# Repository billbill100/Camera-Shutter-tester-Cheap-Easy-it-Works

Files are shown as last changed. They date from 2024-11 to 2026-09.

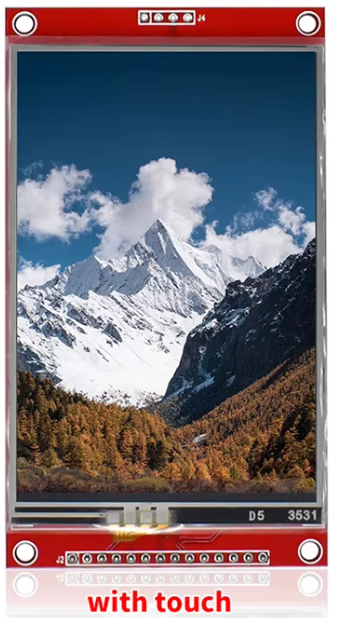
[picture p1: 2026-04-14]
ESP32_V4/3d_print_files/ShutterTesterCase3dPrinted 3_5/photos/Screenshot 2026-04-12 164409.png

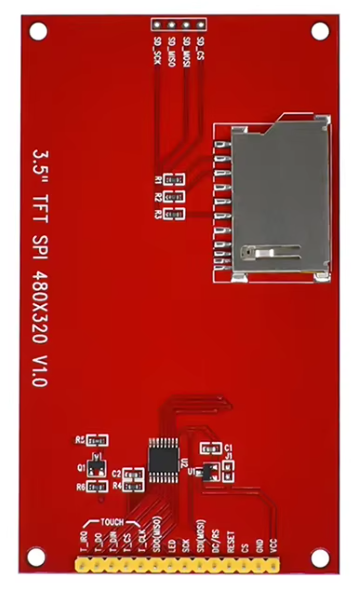
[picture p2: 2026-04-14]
ESP32_V4/3d_print_files/ShutterTesterCase3dPrinted 3_5/photos/Screenshot 2026-04-12 164905.png

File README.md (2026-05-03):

# Camera Shutter Tester -Cheap-Easy-it-Works
ESP32 or Arduino based shutter tester using three sensors (ESP32) or two sensors (Ardiuno).

Important note: - Both ESP32 and Arduino based Shutter Testers are available.

The ESP32 processor is faster and has more flash memory than the Arduino. Therefore the ESP32 based Shutter Tester, allowing greater functionality, including a colour screen, flash sync testing, camera diagnostics and data logging.

The Arduino version is simpler to build, so those with limited experience with microcontrollers & building electronic devices, may find this easier for a first time build.

The Arduino version uses the same processing algorythm as the ESP32 version, so gives accurate shutter meaurements, unlike most (all) of the other Arduino testers found on the interweb.

The latest versions are Version 4 for ESP32 and Version 2 for Arduino.

The use of three lasers & three sensor (two for Arduino) allows for correct travel time measurement for each shutter curtain of a focal plane shutter, which is most important to ensure even exposure across the frame and to detect curtain bouncing.

DIY builds that use a single sensor or Audacity simply will not work. Both shutter curtains must be set to travel at the same speed, which is simply not measurable using just one sensor. Similarly there will always be an inherent error when measuring a single light point with a sensor, which of course will be wider than a single photon. This error can be mathematically calculated and corrected using a simple algorithm, if multiple sensors are used.

The shutter tester is designed to use cheap, easy to obtain parts from Aliexpress. 
A guide to building a suitable enclosure using a project box or optional 3d printing, are included. 
The builder can change or adapt this for their needs, or indeed not use an enclosure at all. Photos of builders different ideas are included.

A comprehensive build guide thread & user group can be found on on Photrio.

# https://www.photrio.com/forum/threads/build-a-shutter-tester-for-focal-plane-shutters-cheap-easy-it-works.197756/

Note both ESP32 and Arduino versions require a one-time pass key. This is supplied free of charge upon request.

On a new build, an authorisation code will be displayed. Send this to me via PM (Photrino is the quickest way) and a user passkey will be sent by return.

I would really be grateful if you start to build the shutter tester, that you go to the Photrio thread and say hi. Also please post photos of your completed tester.

Please refer to Photrio for further build help & to let us know you are building the tester..

 Github has no direct means of contact, my email address is
# bill bill github at gmail dot com
(remove spaces & change @ . )

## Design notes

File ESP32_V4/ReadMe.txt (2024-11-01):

The latest build guides and firmware for Version 4 of the Shutter Tester are listed here.

The build guides have been updated to Version 4, showing the use of JST HX connectors, rather than Dupont wires.

The only hardware change from V3 to V4 is the addition of a rotary encoder 
and the use of JST HX connectors and wiring colours in place of Dupont.
(Which does not effect functionality).

With the addition of a rotary encoder, V3 hardware will work with V4 firmware,
without any other changes.

Note V4 firmware requires the use of a one-time passkey.
This is issued free of charge upon request.

Any questions, ask in the photrio forum
https://www.photrio.com/forum/threads/build-a-shutter-tester-for-focal-plane-shutters-cheap-easy-it-works.197756/page-21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

-----------------------------------------------------------   

Version 4 Firmware

Hardware Changes:-
Rotary Encoder added (mandatory)
LCD Depreciated.

Wiring colour changes to match JT HX pin-headers. Makes wiring neater. 
(Dupont wires can also be used).

Note to convert version 3 hardware to version 4, just add the rotary encoder :o) 

Firmware Changes:-

Baud rate changed to default value of 115200
Leaf shutter testing added.
Sensor spacing is now user-set.
Sensor Reading validity checking updated.
Test result analysing updated (bounce, slow curtain etc).

Alignment screen replaced with all new Setup & Alignment screen.
LCD updated to show & allow change of settings.
PC screen updated to show & allow change of settings.
Rotary encoder used to select & change settings.

Original 'Detailed' TFT screen has been suplemented with a new 'Simple' TFT screen with large typeface, 
replacing the LCD. Changing between Detailed & Simple screen is by a simple button-push, anytime.

Horizontal/vertical shutter selecton removed.
Replaced by user set sensor spacing.

Auto single-sensor sensing removed.
Repaced by user selecting Single Sensor, Leaf or Focal Plane shutter.

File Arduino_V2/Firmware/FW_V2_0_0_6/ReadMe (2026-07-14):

IMPORTANT
This current version 2_0_0_6 is a quick beta version.

Needed to issue it due to issue with 2_0_0_5 would not work with a new Nano board.

Please use this version for now & check back for the fully tested version.

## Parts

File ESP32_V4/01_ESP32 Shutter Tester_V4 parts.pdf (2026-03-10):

I would really be grateful if you start to build the Shutter, that you go to the Photrio thread and say hi. Also please post photos of your completed tester.
Build a shutter tester for Focal Plane shutters - Cheap, Easy & it Works | Page 18 | Photrio.com Photography
Forums (https://www.photrio.com/forum/threads/build-a-shutter-tester-for-focal-plane-shutters-cheap-easy-it-works.197756/page-18)

Please refer to Photrio for further build help

### ESP32 Shutter Tester V4 Parts V1.7 03 03 2026

Below are links to the parts required to make the ESP32 Shutter Tester.

Not all of the parts will be necessary and will depend if you choose to use the project box, or 3d printed case, pcb or expansion board etc. These are detailed with each part.

Links are valid now, but of course could become dead in the future.

Links are for AliExpress suppliers and are a guide only.

Use a supplier who ships to your country.

Note, often if buying from AliExpress, there is a ‘Choice’ free express shipping option, if buying parts over a set value.

### ESP32 NodeMcu board. 38 pin version. USB-C CP2102

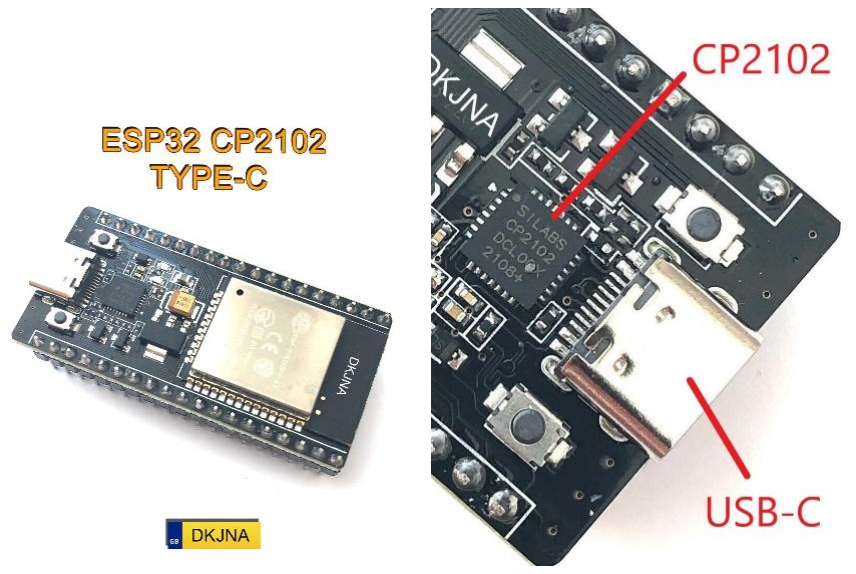
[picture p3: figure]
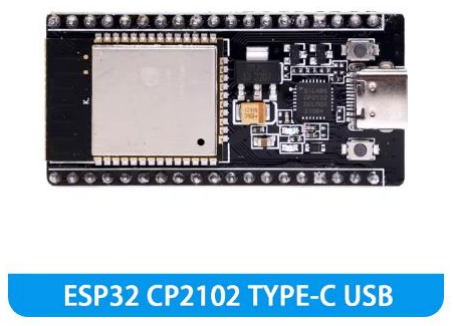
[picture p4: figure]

IMPORTANT. There are multiple variants of this board. Get 38 pin USB-C and CP2102 chip.
The board should NOT have mounting holes. Overall width is 25mm and pin spacing between the rows is 0.9” or 23mm (sometimes listed as 22.5mm)

Note: - The guides have been written for this specific board type. Boards which differ with their USB chip and/or connector may still work, but the guides will not detail different driver installs or pin layout differences.

### ESP32 Expansion (breakout) Board

### ESP32 prototype/breakout board (38 pin screw-terminal version)

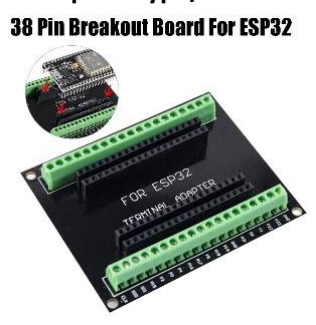
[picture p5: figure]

Note: - this screw type breakout board was originally only available in 38-pin form and for the 22.5mm spaced ESP32 board. However, recently, a 30-pin version has become available, as well as a version for 25mm spaced boards.
This is causing confusion in China. My last few orders of this board have been incorrect. One time sending a purple board with pin headers and most recently a 30-pin board, blue in colour but in a sealed bag marked 38P

Important update There seems to be a big mess-up in China, with both 22.5mm and 25mm expansion boards being mixed. Despite my last few orders from a supplier with measurements written on their board stating it was 22.5mm, the expansion board was for the wider 25mm ESP32 board.

An optional choice is to replace the Expansion Board with a custom PCB.
Details below:

A custom pcb replacing the expansion board has been designed. Both the ESP32 and tft screen plug directly into it, with all wiring between the two, pre-connected on the board.
All other wiring, for the sensor etc, are accessed by screw-terminals as per the expansion board.

The pcb can only be ordered directly from the originator of The Shutter Tester (contact via Photrio).
See additional ‘The Shutter Tester pcb’ document on Github.

There is a newer V4 ESP32 board available. It has 25mm spacing, USB-C and the 2102 USB driver.
It is also cheaper. One issue with this board is that the pcb is too narrow to mount directly onto the TFT mounting bolts. So the 3d printed expansion board frame will be required.
Personally, I have not yet tried it, but it may be the way forward to overcome the issues with the current expansion board. Link is to the Aliexpress page. If you try it, get the 32D Type-C KIT which includes ESP32 board and the expansion board.
ESP32 Development Board with GPIO Expansion Board Kit ESP32-WROOM-32D BT Wifi Module USB Type-C 38PIN CP2102 ESP32-DevKitC - AliExpress 502 (https://www.aliexpress.com/item/1005007820261192.html?mp=1) ----------------------------------------------------------------------------------------------------------------------------------------------

Update 06/02/2026
A recent builder has used this link and reports they ordered the expansion board (not breakout board) and the ESP32 from here and they were the correct ones.

ESP32 Nodemcu ESP32 Expansion Board ESP32-S 32Mbit SPI Flash ESP32 Bluetooth Wifi ESP 32 Bluetooth (https://www.aliexpress.com/item/1005008419095315.html)

Module ESP32 30Pin 38Pin - AliExpress (https://www.aliexpress.com/item/1005008419095315.html)

Laser tx & rx module.
Three Laser tx and rx module pairs are required.

The sensor is supplied loose. ENSURE YOU INSERT IT THE CORRECT WAY ROUND!!!. Little bubble lens points towards the header pins.

Arduino Laser Sensor Receiver | Laser Transmitter Module Arduino - 10pcs/set Sensor - Aliexpress (https://www.aliexpress.com/item/1005003318800536.html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)

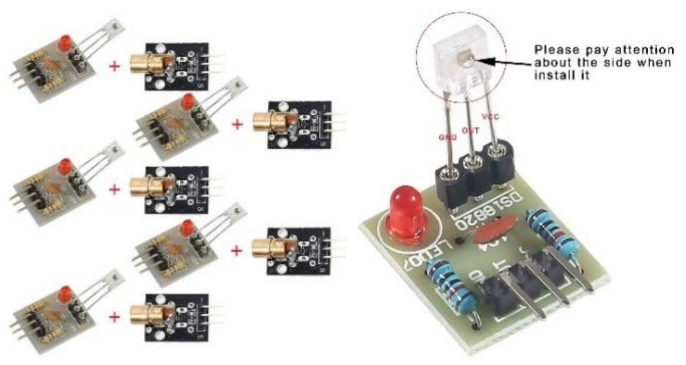
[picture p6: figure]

Buttons.
Below is a link to buttons which may be purchased as a 6-pack. Note they melt very easily with a soldering iron, so one must be proficient & quick when making the soldered joints. An alternate is to buy a 5-button module, which uses Dupont/JST header pins.

6piece Mini 12mm Waterproof Momentary On/off Push Button Round Switch Pbs-33b Kit White Black Red Yellow Blue Green - AliExpress (https://www.aliexpress.com/item/1005006228814305.html)

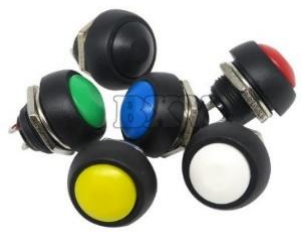
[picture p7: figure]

JST XH 2.54MM Connector kit.
This kit comes with connectors pre-crimped onto the wires. This allows the connectors to simply be pushed into the plastic housings, allowing for different connector sizes and colour combinations to be made.

Note: - There are no brown wires in these kits. (see below)*

The TFT needs a 14-pin connector. This is made by using two 7-way connectors from the kit and carefully cutting off the lips on the connectors, so they sit side-by-side. (Or you can buy a separate 8-way JST XH connector and use in combination with a 5-way connector, which fit either side of the unused pin on the TFT).

2.54mm XH Connector Socket Kit with 22AWG Pre-Crimped Wire Cable JST XH 2/3/4/5/6/7 Pin Housing Male Female Adapter Cable - AliExpress 13 (https://vi.aliexpress.com/item/1005008117970148.html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)

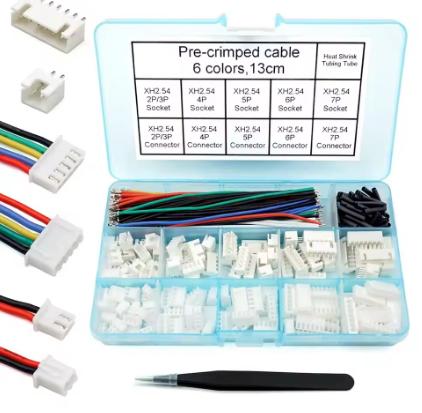
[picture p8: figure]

*JST XH 2.54mm wires. Single colours, Select 30cm Double Head Brown. OPTIONAL – See below
Note: The schematic uses Brown colour to distinguish 3V power and 5V (Red).

To save buying additional wires, which have additional postage costs,
Red can be used for both 3V and 5v, but BE CAREFUL with connections.

10Pcs SH1.0mm Jst 1.25mm PH2.0mm XH 2.54mm Terminal Wire Single / Double Head Electronic Connecting Cable Without Shell 10-30CM - AliExpress 13 (https://vi.aliexpress.com/item/1005006316801315.html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)

TFT display.

### 4.0 inch SPI Touch screen Module 480*320 TFT display ILI9488

Board size is 108.04 X 61.74

Note: - there are many similar panels but they have different driver chips (ILI9488), the Shutter Tester only works with this specific screen. Please ensure you correctly order the screen. The AliExpress web sites often list similar but different boards.

New 4.0 inch SPI serial port LCD Touch screen Module 480*320 (Free Shipping)TFT display ILI9488 HD Electronic STM32 ESP32 AR C51 - AliExpress 502 (https://vi.aliexpress.com/item/1005005791515997.html)

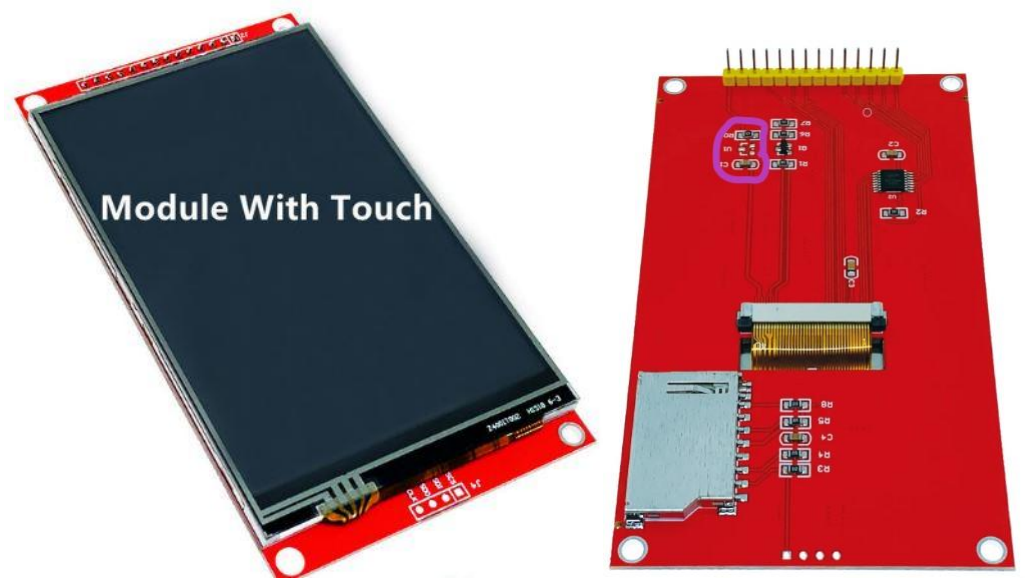
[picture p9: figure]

Rotary Encoder.
Ensure you purchase the one mounted onto the blue pcb. As this has in-built pullup resisters & capacitors.
Rotating Potentiometer Knob Cap Digital Control Module Rotary Encoder Controller Switch 5V Diy Kit EC11 For Arduino PCB Board - AliExpress (https://www.aliexpress.com/item/1005006332290643.html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)

### USB extension cable. 0.2M length. (Optional)

Makes a neat job by bringing the USB port of the ESP32 board to the side of the project box.

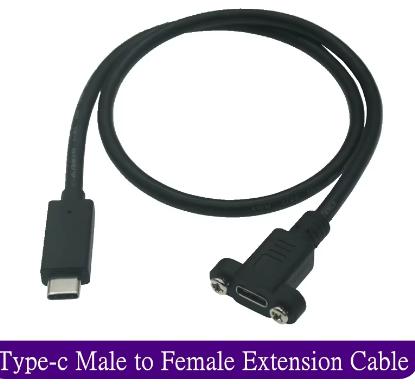
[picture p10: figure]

1M 0.5M Panel Mount Type-C USB-C Male To Female Extension Cable With Screw Hole Lock Connector Cable Spacing 18mm - AliExpress 7 (https://vi.aliexpress.com/item/1005003311183241.html)

Light sensor. (Optional).
GY-301 LIGHT SENSOR MODULE
TZT GY-302 BH1750 BH1750FVI light intensity illumination module for arduino 3V-5V (aliexpress.com) (https://www.aliexpress.com/item/1005005850310036.html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)


LED Matrix Module. (Optional).
Gives a visual indication of shutter speed, works like the old idea of photographing a scanning CRT.

New version – requires header pins soldering
MAX7219 Dot Matrix Microcontroller Display Module Together For Arduino - AliExpress 502 (https://vi.aliexpress.com/item/1005006189776556.html?scm_id=1007.40000.326746.0&scm-url=1007.40000.326746.0)


Project Box. (not required if 3d printing a case).
There are all sorts of shapes & sizes of project boxes. The 158 x 90 x 60 is a good size.
The screen must be positioned as high as possible, to leave enough space below, for two rows of buttons. A suggested layout & template can be found in the ‘Build a Box’ document.
Black Box Outdoor Waterproof Case Plastic Box Electronic Project Case Instrument Waterproof Junction Box Housing - AliExpress (https://www.aliexpress.com/item/1005005622148025.html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)


Note: a 3d printable enclosure is also available. Files are in the Github.

Project box for Light-Meter 55 X 35 X 20. (Optional).
If using the Light-Meter module, this box is the ideal size.
1pc Waterproof Black/white Housing Instrument Case ABS Plastic Project Box Storage Case Enclosure Boxes Electronic Supplies - AliExpress (https://vi.aliexpress.com/item/1005005467340473.html)


Note: - if using the LED matrix, a suitable project box will also be required.

### PC sync cable (flash) (Optional)

For testing flash synchronising. A 3.5mm socket will also be required.


### 3.5mm socket. (Optional)

If using the Flash Sensor, a 3.5MM socket is required. PJ-391 for the sockets.
10PCS 2.5 3.5MM Headphone Jack Audio Video Female Dual Channel Stereo Jack Jack Socket Stereo Solder Panel Mount PJ-210B PJ-392 - AliExpress (https://vi.aliexpress.com/item/1005006181883514.html?mp=1)

Multicore Wire.
Used to connect the sensors to the breakout board and button wiring.
5/10Meter 22 AWG 2Pin 3Pin 4Pin 5Pin 6Pin Electronic Cable Extension Wire Color Line for 5050 3528 RGBW RGB CCT LED Strip Lights - AliExpress 13 (https://vi.aliexpress.com/item/1005007156114505.html?mp=1)

More expensive but has outer insulation. Good for the external cable between project box & sensors.
5-50m LED Strip Extension Cable Flexible Multi 2 3 4 5 6 7 8 9 10 Core Insulate Audio Electrical Wire For Speaker LED Lights Bar - AliExpress 13 (https://vi.aliexpress.com/item/1005006340775911.html?scm_id=1007.40000.327270.0&scm-url=1007.40000.327270.0)

Connector-block - 2 pole. (Not required for PCB version)
There are many 3V & 0V wires to be connected. The quickest way is to use a lever-locking connector as shown below. As the wires are thin, many can be put into each terminal, so a 2-terminal type is fine. Use one with more terminals if you like

Alternates are to the solder the wires together, or use a joining block.

10-75pcs Orange Universal Type Quick Plug-in Terminals,Electrical Equipment Connectors,Wire Connector Terminals,250V/32A - AliExpress (https://www.aliexpress.com/item/1005006271613810.html?scm_id=1007.40050.354490.0&scm-url=1007.40050.354490.0)


Shrink Tube. (Optional).
It is useful cut into small lengths of 5mm, and placed along the cables, to hold them into a bunch, for neater wiring. Note shrink tube also comes with the JST connector kit.

Also useful for covering soldered joints on wires, if using JST connectors for the sensors, for example, which then need soldering to the multicore cable.

127pcs/lot 2:1 Thermoresistant tube Shrink wrapping Black heat shrink Sleeving set Wire Cable Polyolefin Wrap Tubing - AliExpress (https://vi.aliexpress.com/item/1005006381007308.html)


Plug & Sockets.
The cable to the sensors/Lasers & Light-meter can be hardwired directly to the expansion board or connected via plugs & sockets.

Use 8 pin plugs & sockets for cabling to the Sensor/Laser frame. Five of the eight pins will be used.

There will be three spare pins. Another 8-pin plug & socket can be used for the light senor, using the three spare pins and sharing the 0V pin.

Ensure that the 3.3V and 5V are given their own dedicated pins and these pins are not used for data in another connector.

If using the LED matrix, use a connecter with a different number of pins, to avoid the possibility of it being plugged in to the wrong socket.

An alternate would be using a different connector type for each of the outputs (8-pin for sensor/Laser frame, six-pin for light-meter, 5-pin for Matrix, for example)

Solder Connector DIN 3 4 5 6 7 8 Pin DIN Male Female Plug with Plastic Handle + Female Socket Hulled Panel Mount Chassis a1 - AliExpress 13 (https://vi.aliexpress.com/item/1005004311168264.html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)


### M3 Bolts, Nuts, Washers. 25mm & 12MM Length Stainless Steel

M3 bolts can be used to mount the tft screen into the project box or 3d printed case. Slightly elongating the mounting holes on the expansion board, allows it to also be easily mounted onto the same bolts. 25mm length is ideal for this. 12mm can be used to mount the Din sockets, if using them.
Don’t forget to also order washers & nuts.

Nuts & bolt set
M2 M3 M4 M5 M6 Nuts and Bolts Set 304 Stainless Steel Hexagon Button Hex Socket Fairing Bolt Assortment Kit Thread Allen Screws (https://vi.aliexpress.com/item/1005005377559662.html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)

Bolts only

5-50p ISO7380 M2 M2.5 M3 M4 M5 M6 M8 304 A2 Round Stainless Steel or Black G10.9 Hex Socket screw Button Head Allen Bolt Screws - AliExpress 13 (https://vi.aliexpress.com/item/32810852732.html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)

Washers
GB97 DIN125 A2-70 304 Stainless Steel Flat Washer Plain Gasket M1.6 M2 M2.5 M3 M3.5 M4 M5 M6 M8 M10 M12 M14 M16 M18 M20 M22 M24 - AliExpress 13 (https://vi.aliexpress.com/item/32975752411.html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)

Nuts
100pcs/lot Metric thread DIN934 M2 M2.5 M3 M3.5 M4 M5 M6 Steel Hex Nuts - AliExpress 13 (https://vi.aliexpress.com/item/1005007856981951.html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)

Lifting platform for adjusting height of camera. (3d print files available, to make top, to hold camera)
Plastic Lift Table Woodworking Carving Laser Level Bracket Plastic or Aluminum Meterial Device Height Adjustment Lift Platform - AliExpress 1420 (https://www.aliexpress.com/item/1005010660465390.html)


Items for 3d printed case and 3d printed sensor & Laser enclosure. (Optional).
Lasers. Required for the 3d printed the Laser enclosure.
Order the 5v Lasers.
5pcs Adjustable Laser Diode 650nm 6mm 3/5V 5 Million Watt Red Point Line Laser Diode Module Red Copper Head
- AliExpress 1420 (https://www.aliexpress.com/item/1005003538326411.html)


Pcb strip-board. Required for the 3d printed sensor enclosure.
This board has each row of holes electrically connected.
5/10PCS DIY 6.5x14.5 6.5*14.5CM Prototype Paper PCB Universal Experiment Matrix Circuit Board Single Row Continuous Hole - AliExpress 502 (https://www.aliexpress.com/item/1005008734573412.html)


0.1uF Capacitors. (104 100NF) Required for the 3d printed sensor enclosure.
100PCS 100nF 0.1uF 0.1 uF 104 50V 2.54mm Dip Mono Monolithic Capacitors - AliExpress (https://www.aliexpress.com/item/1005005610707847.html?curPageLogUid=fK9XBGJN9GK5)


10k resisters Required for the 3d printed sensor enclosure.
100PCS/Lot Metal Film Resistor 1/4W 1% 100R 220R 1K 1.5K 2.2K 4.7K 10K 22K 47K 100K 100 220 1K5 2K2 4K7 Ohm Resistance 1R~22M - AliExpress (https://www.aliexpress.com/item/1005006898731441.html?curPageLogUid=0MNUTMG3vVjt)


2mm screw selection box. Used to assemble the case and enclosures.
800pcs M2(2mm) Self Tapping Wood Carbon Steel Phillips Pan Head Self Tapping Screws Assortment Kit M2*4/5/6/8/10/12/16/20mm - AliExpress 13 (https://www.aliexpress.com/item/1005008090724184.html)


M5 X 35mm nut, bolt & washer with 10mm hex head.
This is for the camera steady, which sits on the lifting platform.

### _________________________________________________

### Additional useful parts

Lifting platform. Used to place the camera on and allows height adjustment.
Plastic Lift Table Woodworking Carving Laser Level Bracket Plastic or Aluminum Meterial Device Height Adjustment Lift Platform - AliExpress 1420 (https://www.aliexpress.com/item/1005010660465390.html)


Drill bits for making holes in the project box. (Not required for 3d printed case)
3MM for bolts, 7mm for encoder & flash socket, 13mm for the buttons, 15MM for Din sockets.

3-12mm Three-point Woodworking Drill Hole Opener Twist Drill Bit Practical Wood Milling Cutter Multifunctional Drilling Tools - AliExpress (https://www.aliexpress.com/item/1005006103163521.html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)

13mm bit.
10-35mm Woodworking Twist Drill Bit Set Long Four-Slot 6.35mm Shank Carbide Drill Bit Hole Saw For Door Lock Wood Slotting Tools (aliexpress.com) (https://vi.aliexpress.com/item/1005003944211081.html)

Glue Gun.
Cheap glue gun, but surprisingly it works ok.
20W Hot Melt Glue Gun DIY Mini Household Industrial Guns Heat Temperature Thermo EU Electric Repair Tool Use 7mm Glue Sticks - AliExpress (https://www.aliexpress.com/item/1005005795878015.html)

Don’t forget the glue :o)
T TOVIA 60pcs/120pcs Hot Melt Glue Sticks 7mm Hot Glue Sticks Rod for Craft Album Repair Tools Hot Glue Gun Sticks - AliExpress (https://vi.aliexpress.com/item/1005005713317179.html?mp=1)

### Wire Strippers. Model 3001D

The JST HX wires are very thin 22AWG. A good quality wire stripper will be required. An alternate is to use a sharp scalpel or Stanley knife blade

Pro'sKit 8PK-3001D 8PK-3002D high quality electronic wire stripper cutting pliers (AWG 30/28/26/24/22/20 precision pliers - AliExpress 1420 (https://vi.aliexpress.com/item/1005007370026286.html?mp=1)

Stanley knife & plasters trowel.
To safely make square cut-out for tft in the project box. Source locally.

Soldering Iron Kit.
Cheap soldering iron kits are available on Aliexpress. I found the tips are very loose & the internet mod is to wrap a strip of aluminium cooking foil around the ceramic heater, to reduce the gap. However, it is far better to buy a genuine branded product, Weller or Antex (not a cheap knock off)

Ensure you buy a roll of Lead/Tin solder, not the horrible lead-free stuff, which needs a higher temperature to melt and does not flow very well.

Update notes:
V 1.5 simplified build by removing pre-made JST cables, removing orange wire (substituted with blue) Breakout board/pcb option added
Optional 3d printed parts added

V1.6 added warnings around the mixed 22.5 and 25mm Expansion boards.

V1.7 Updated links, added 3d printed parts, removed light-sensor-gate.

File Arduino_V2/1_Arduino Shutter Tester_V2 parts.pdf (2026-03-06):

The Shutter Tester – Arduino V2 | Doc 1.3 02/03/26

Links are provided to AliExpress suppliers. The links (& prices) are valid now, but of course could become dead in the future. Suppliers chosen, offer ‘choice’ which means when the total order is over £8, shipping is free.

AliExpress is by far the cheapest source for parts. However, they are not good at item descriptions or ensuring the correct part is dispatched. Parts can be sourced on Amazon or Ebay, but prices are higher.

Arduino Nano V3. USB C.
The USB-C option is nice as the USB extension cable (listed further down) can be used. They are available with the header pins soldered (welded) or loose. £2.37

1-10pcs Type-C USB Nano 3.0 With the bootloader compatible Nano controller for arduino CH340 USB driver 16Mhz ATMEGA328P - AliExpress 502 (https://vi.aliexpress.com/item/1005007094357913.html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)


Arduino Nano Expansion/prototype board.
Makes wiring easy as all the pins on the Arduino board are taken to screw terminal connectors.

Note: - The listing does not state if this board comes pre-soldered, although the photos seem to indicate that it is. £1.01

1-10pcs Type-C USB Nano 3.0 With the bootloader compatible Nano controller for arduino CH340 USB driver 16Mhz ATMEGA328P - AliExpress 502 (https://vi.aliexpress.com/item/1005007094357913.html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)


Laser tx & rx module. Two of each module required.
The sensor is supplied loose. ENSURE YOU INSERT IT THE CORRECT WAY ROUND!!!. Little bubble lens points towards the header pins. £0.79 £0.99

KY-008 650nm Laser Transmitter Module with Laser Sensor Module Non-Modulator Tube Laser Receiver Module Kit -AliExpress 502 (https://vi.aliexpress.com/item/1005006678207269.html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)

LCD 2004.
Ensure you get a module that includes the IIC or I2C module and is the four line (not two line) display. £3.63

The IIC module can be seen on the lower photo, it is the small dark pcb on the back. (or ‘black’ in Chinglish :o)

LCD2004 2004 LCD Module Blue/Green/White Screen 20X4 Character LCD Display IIC I2C Serial Interface Adapter Module for Arduino - AliExpress 502 (https://vi.aliexpress.com/item/1005006520514745.html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)

Buttons.
Two buttons are required for Arduino version. There are all sorts of buttons available for you to choose, depending on your fial layout of The Shutter Tester. Below are possible options.

This is a very cheap button module, ideal for prototype work and getting things working quickly. This module is not suitable for mounting into a case. One pin on£0.65

1-10PCS 1x4 4-Button Independent Keypad Module DIY Kit for Arduino Raspberry Pi STM32 Electronics Projects STEM
- AliExpress (https://www.aliexpress.com/item/1005009801434177.html?curPageLogUid=XhgSAREiJRQJ)


Loose buttons.
These fit neatly into a project box or the 3d printed case, requiring a 13mm hole to be drilled, or the 3d printed case (which already has 13mm mounting holes). £1.73
Note: - They will require wires to be soldered to the terminals of the buttons.

6piece Mini 12mm Waterproof M1mentary On/off Push Button Round Switch Pbs-33b Kit White Black Red Yellow Blue Green - AliExpress 502 (https://vi.aliexpress.com/item/1005006228814305.html)


Wiring for LCD module.
The neatest way is to use a 4 Pin JST XH pre-made connector.
10cm length is fine for the LCD. The 20cm length is cheaper and the extra length maybe useful for other projects. £0.96

5Sets JST XH2.54 XH 2.54mm Wire Cable Connector 2/3/4/5/6/7/8 Pin Male and Female Plug Socket 10cm 20cm Wire Length 26AWG - AliExpress 13 (https://vi.aliexpress.com/item/1005007460897865.html)

Wiring for Button module.

The same 4-way JST-XH connectors as used for the LCD, can be used for the button module. Do not use the red wire (to avoid confusion with +5V)

### Wiring for Lasers & Sensors

The individual 5V & the 0V pins on the modules can be looped together, either by soldering a wire to the pins or using Dupont or JST XH connectors (Order 3 pin JST HX connectors, four required) and joining them together with terminal block or soldering. £1.70
Be careful as the colours will not match red for +v, Black for 0V etc

5Sets JST XH2.54 XH 2.54mm Wire Cable Connector 2/3/4/5/6/7/8 Pin Male and Female Plug Socket 10cm 20cm Wire Length 26AWG - AliExpress 13 (https://vi.aliexpress.com/item/1005007460897865.html)


Multicore Cable.
This connects the Lasers and sensors to the screw-terminal board, 4 core is required. Keep the length between sensors and the screw-terminal board short to avoid voltage drop and interference (40cm should be fine for length). Plenty spare as sold in 5 metre length £1.90

The wire can also be used for ‘hook-up’ wire if using the loose buttons.

5/10Meter 22 AWG 2Pin 3Pin 4Pin 5Pin 6Pin Electronic Cable Extension Wire Color Line for 5050 3528 RGBW RGB CCT LED Strip Lights - AliExpress 13 (https://vi.aliexpress.com/item/1005007156114505.html)


Connector Block. (Optional).
These connectors can be used to avoid soldering. £1.93
Join all of the 5V wires from the sensors & Lasers together and to the multicore cable, using one of these connectors. Doing the same for the 0V wires.
The two individual sensor output wires can also be connected to the multicore cable with these connectors. connecting
Useful if avoiding soldering.

As the wires used for the project are thin, two or three wires easily fit into each terminal, so 2 or 3 terminal connectors are fine. (The terminals in the connector are all commoned together)

Note: - These connectors are fine for low voltage and current applications, but I would not recommend Chinese knock-offs for house wiring or heavy load applications.

10-75pcs Orange Universal Type Quick Plug-in Terminals,Electrical Equipment Connectors,Wire Connector Terminals,250V/32A - AliExpress 13 (https://vi.aliexpress.com/item/1005006271613810.html)


USB Cable. (Optional).
If building into a project box (or the 3d printed case, which is designed to fit this cable, with the cut-out pre-made), this is a neat way of bringing the USB connector to the outside of the box. £2.54
1M 0.5M Panel Mount Type-C USB-C Male To Female Extension Cable With Screw Hole Lock Connector Cable Spacing 18mm - AliExpress 7 (https://vi.aliexpress.com/item/1005003311183241.html)


Project Box. 158-90-60 (Optional).
To house the project. £5.09

Black Box Outdoor Waterproof Case Plastic Box Electronic Project Case Instrument Waterproof Junction Box Housing - AliExpress (https://www.aliexpress.com/item/1005005622148025.html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)


### M3 Bolts, Nuts, Washers. 25MM Length Stainless Steel. (Optional)

M3 x 25mm bolts are used to mount the LCD screen into the project box or 3d printed case. They can also be used to mount the Din connector, but 12MM length is better for this. Don’t forget to also order washers & nuts.

Nuts & bolt set £1.89
M2 M3 M4 M5 M6 Nuts and Bolts Set 30
4 Stainless Steel Hexagon Button Hex Socket Fairing Bolt Assortment Kit Thread Allen Screws (https://vi.aliexpress.com/item/1005005377559662.html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)

Bolts only
5-50p ISO7380 M2 M2.5 M3 M4 M5 M6 M8 304 A2 Round Stainless Steel or Black G10.9 Hex Socket screw Button Head Allen Bolt Screws - AliExpress 13 (https://vi.aliexpress.com/item/32810852732.html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)

Washers
GB97 DIN125 A2-70 304 Stainless Steel Flat Washer Plain Gasket M1.6 M2 M2.5 M3 M3.5 M4 M5 M6 M8 M10 M12 M14 M16 M18 M20 M22 M24 - AliExpress 13 (https://vi.aliexpress.com/item/32975752411.html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)

Nuts
100pcs/lot Metric thread DIN934 M2 M2.5 M3 M3.5 M4 M5 M6 Steel Hex Nuts - AliExpress 13 (https://vi.aliexpress.com/item/1005007856981951.html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)

Plug & Sockets. (Optional).
The cable to the sensors can be hardwired directly to the breakout board or plugs & sockets used. £1.04 + £0.99

Six or eight pin connector is recommended, as this is not a common size that may be found in households.

Solder Connector DIN 3 4 5 6 7 8 Pin DIN Male Female Plug with Plastic Handle + Female Socket Hulled Panel Mount Chassis a1 - AliExpress 13 (https://vi.aliexpress.com/item/1005004311168264.html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)


Shrink Tube. (Optional).
It is useful cut into small lengths of 5mm, and placed along the cables, to hold them into a bunch, for neater wiring.

Also useful for covering soldered joints on wires, if using JST connectors for the sensors, for example, which then need soldering to the multicore cable.

If using the DIN connector above, a short length is placed over the soldered connections, to avoid shorts between pins or should a wire come loose. £1.13
Black Heat Shrink Tube Kit Thermoresistant Tubing Shrink Wire Wrapping Electrical Connection Cable Insulation Sleeves Protecter - AliExpress (https://www.aliexpress.com/item/1005008895688869.html?curPageLogUid=705ohArMaXJb)

Lifting platform for adjusting height of camera. (3d print files available, to make top, to hold camera)
Plastic Lift Table Woodworking Carving Laser Level Bracket Plastic or Aluminum Meterial Device Height Adjustment Lift Platform - AliExpress 1420 (https://www.aliexpress.com/item/1005010660465390.html)


### Additional parts required if using the 3d printed sensor and Laser Enclosures

Lasers. Required for the 3d printed the Laser enclosure. Order the 5v Lasers.
5pcs Adjustable Laser Diode 650nm 6mm 3/5V 5 Million Watt Red Point Line Laser Diode Module Red Copper Head
- AliExpress 1420 (https://www.aliexpress.com/item/1005003538326411.html)


Pcb strip-board. Required for the 3d printed sensor enclosure.
This board has each row of holes electrically connected.
5/10PCS DIY 6.5x14.5 6.5*14.5CM Prototype Paper PCB Universal Experiment Matrix Circuit Board Single Row Continuous Hole - AliExpress 502 (https://www.aliexpress.com/item/1005008734573412.html)


0.1uF Capacitors. (104 100NF) Required for the 3d printed sensor enclosure.
100PCS 100nF 0.1uF 0.1 uF 104 50V 2.54mm Dip Mono Monolithic Capacitors - AliExpress (https://www.aliexpress.com/item/1005005610707847.html?curPageLogUid=fK9XBGJN9GK5)

10k resisters Required for the 3d printed sensor enclosure.
100PCS/Lot Metal Film Resistor 1/4W 1% 100R 220R 1K 1.5K 2.2K 4.7K 10K 22K 47K 100K 100 220 1K5 2K2 4K7 Ohm Resistance 1R~22M - AliExpress (https://www.aliexpress.com/item/1005006898731441.html?curPageLogUid=0MNUTMG3vVjt)

2mm screw selection box. Used to assemble the case and enclosures.
800pcs M2(2mm) Self Tapping Wood Carbon Steel Phillips Pan Head Self Tapping Screws Assortment Kit M2*4/5/6/8/10/12/16/20mm - AliExpress 13 (https://www.aliexpress.com/item/1005008090724184.html)


### Additional useful parts

Drill bits for making holes. 3MM for bolts, 13mm for the buttons, 15MM for Din sockets.
Note only required for the project box.

3-12mm Three-point Woodworking Drill Hole Opener Twist Drill Bit Practical Wood Milling Cutter Multifunctional Drilling Tools - AliExpress (https://www.aliexpress.com/item/1005006103163521.html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)

13mm bit.
10-35mm Woodworking Twist Drill Bit Set Long Four-Slot 6.35mm Shank Carbide Drill Bit Hole Saw For Door Lock Wood Slotting Tools (aliexpress.com) (https://vi.aliexpress.com/item/1005003944211081.html)

Glue Gun.
Cheap glue gun, but surprisingly it works ok. £2.80
20W Hot Melt Glue Gun DIY Mini Household Industrial Guns Heat Temperature Thermo EU Electric Repair Tool Use 7mm Glue Sticks - AliExpress (https://www.aliexpress.com/item/1005007481144685.html?curPageLogUid=sLO1t0HJl4Td)

Don’t forget the glue :o) £3.33
T TOVIA 60pcs/120pcs Hot Melt Glue Sticks 7mm Hot Glue Sticks Rod for Craft Album Repair Tools Hot Glue Gun Sticks - AliExpress (https://vi.aliexpress.com/item/1005005713317179.html?mp=1)

### Wire Strippers. Model 3001D

The JST HX wires are very thin 22AWG. A good quality wire stripper will be required. An alternate is to use a sharp scalpel or Stanley knife blade. £10.79

Pro'sKit 8PK-3001D 8PK-3002D high quality electronic wire stripper cutting pliers (AWG 30/28/26/24/22/20 precision pliers - AliExpress 1420 (https://vi.aliexpress.com/item/1005007370026286.html?mp=1)

Stanley knife & plasters trowel.
To safely make square cut-out for the LCD in the project box. Source locally.

Soldering Iron Kit.
Cheap soldering iron kits are available on Aliexpress. I found the tips are very loose & the internet mod is to wrap a strip of aluminium cooking foil around the ceramic heater, to reduce the gap. However, they are rubbish and it is far better to buy a genuine branded product, Weller or Antex (not a cheap knock off)

Solder.
Get lead-based solder 60/40. Lead free solder is awful to work with.

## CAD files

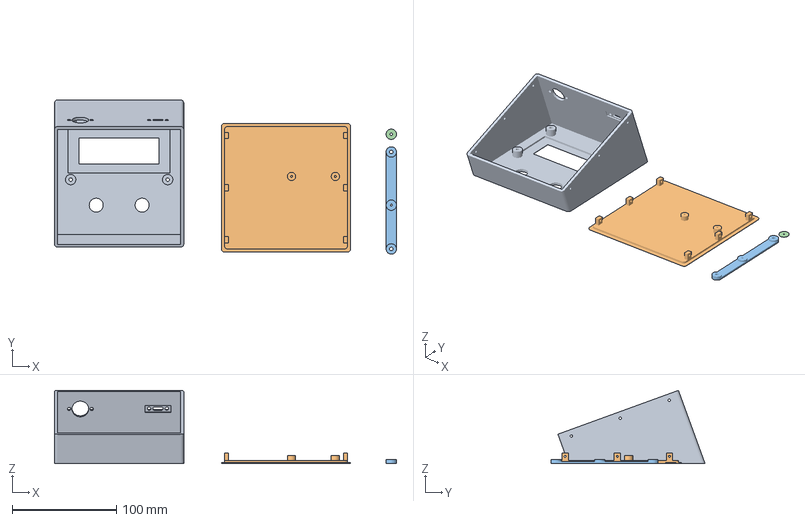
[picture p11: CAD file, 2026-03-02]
Arduino_V2/3d print files/Shutter_Tester_Arduino_Case.3mf
328.0 x 148.0 x 70.3 mm

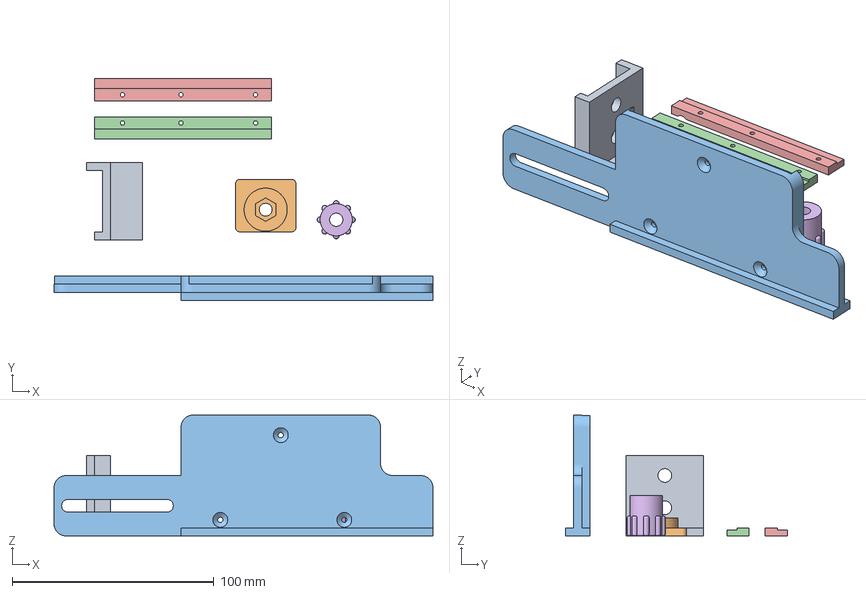
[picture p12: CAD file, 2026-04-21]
ESP32_V4/3d_print_files/camera_steady/camera_steady.3mf
188.0 x 110.0 x 60.0 mm

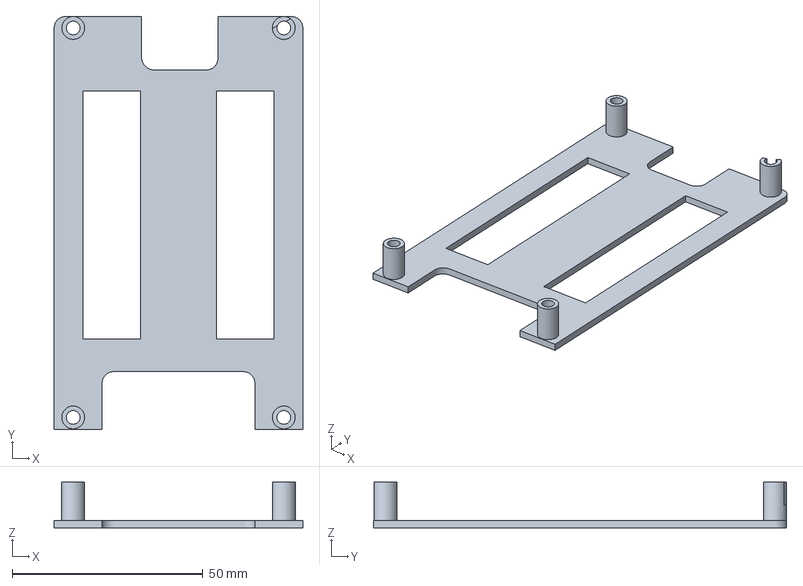
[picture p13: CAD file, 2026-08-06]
ESP32_V4/3d_print_files/Expansion board frame/TheShutterTester_tft_exp_frame.3mf
65.2 x 108.2 x 12.0 mm

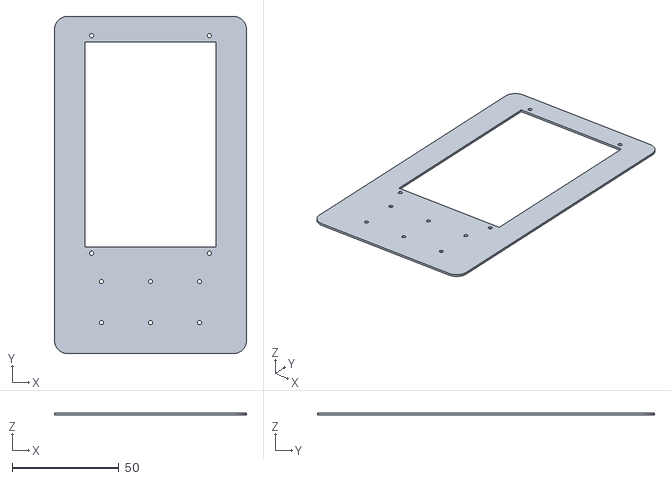
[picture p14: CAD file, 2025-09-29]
ESP32_V4/3d_print_files/project_box_template v6.stl
90.0 x 158.0 x 1.00

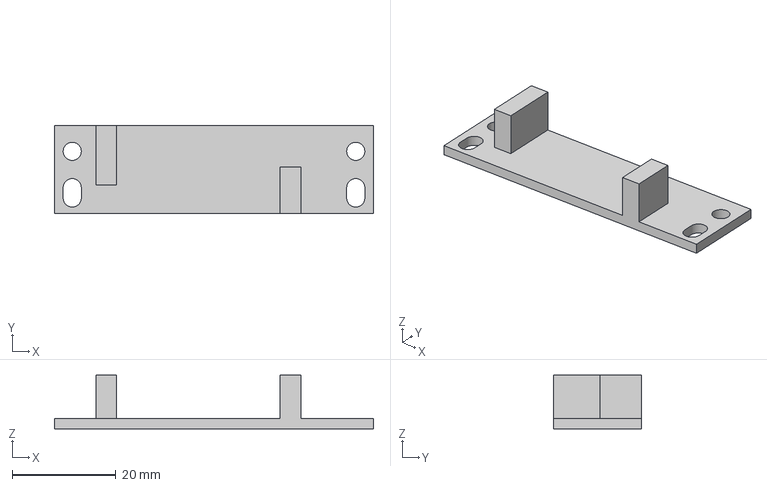
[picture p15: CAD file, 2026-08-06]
ESP32_V4/3d_print_files/ShutterTester_pcb_spacer/4inch TFT pcb spacer.3mf
61.5 x 17.0 x 10.4 mm

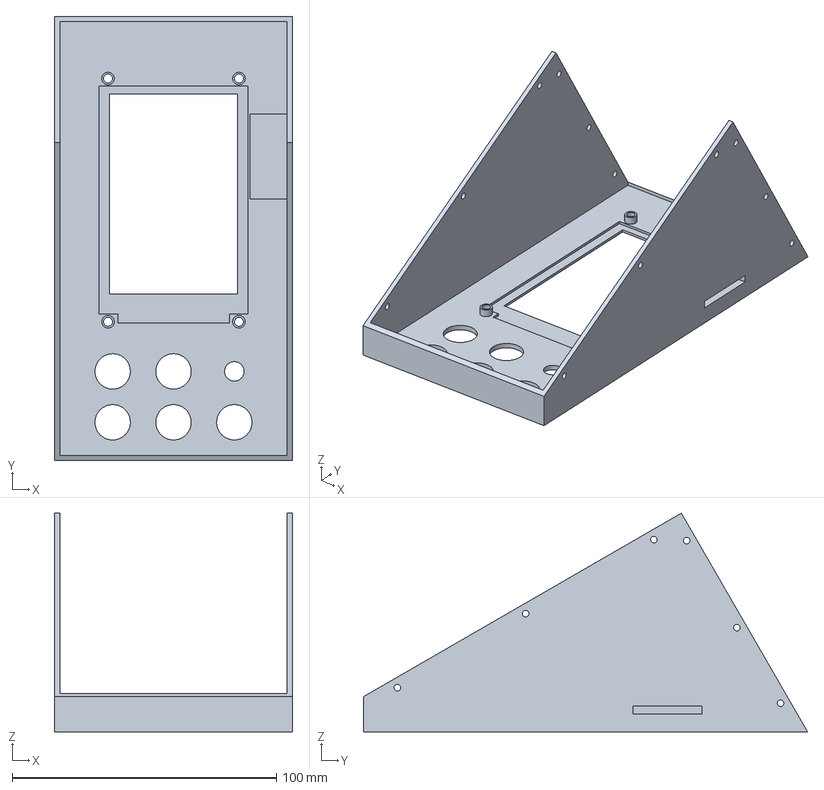
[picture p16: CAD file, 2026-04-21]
ESP32_V4/3d_print_files/ShutterTesterCase3dPrinted 3_5/TheShutterTester3_5_screen.3mf
90.0 x 168.0 x 82.7 mm

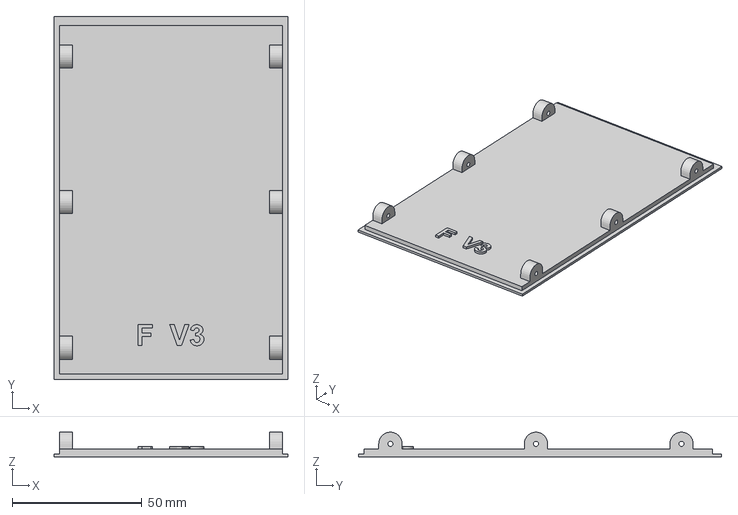
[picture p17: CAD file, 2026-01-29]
ESP32_V4/3d_print_files/ShutterTesterCase3dPrinted/ShutterTestterBottomV3.3mf
90.0 x 139.9 x 9.48 mm

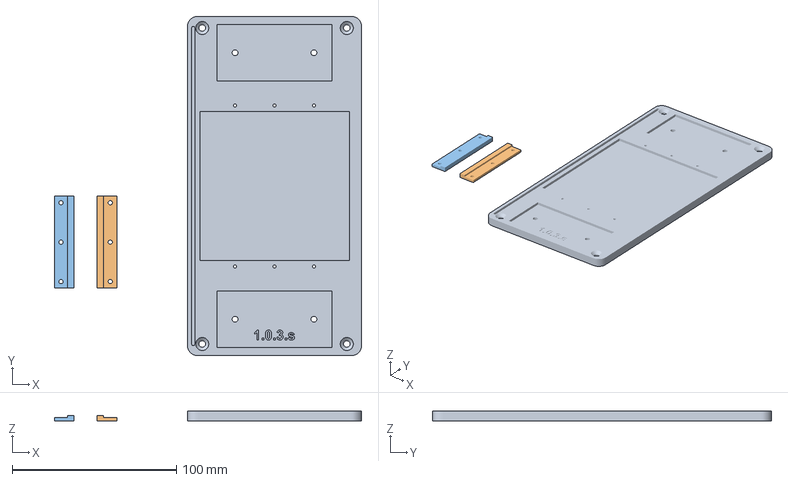
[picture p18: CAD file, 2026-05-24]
ESP32_V4/3d_print_files/ShutterTesterFrame/shutter_tester_base103_smaller.3mf
187.0 x 206.4 x 6.00 mm

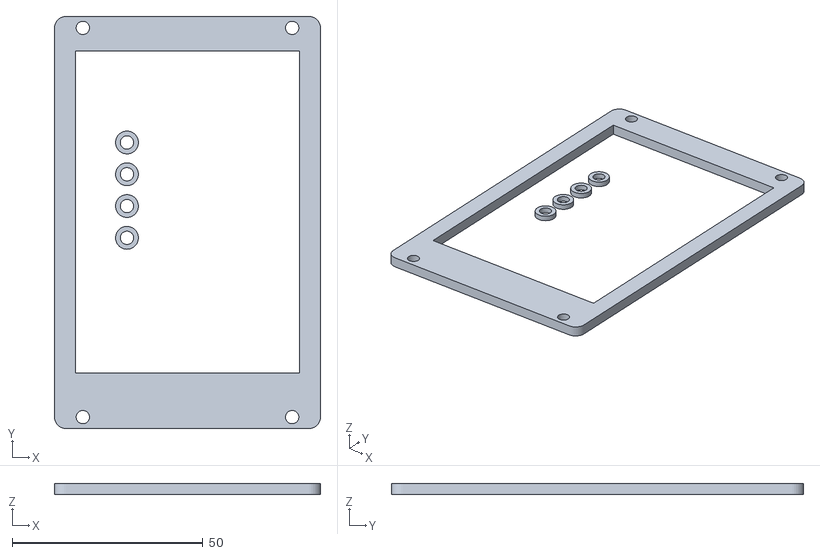
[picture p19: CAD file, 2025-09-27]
ESP32_V4/3d_print_files/4inchTFTbezel v7.stl
69.7 x 108.0 x 3.00

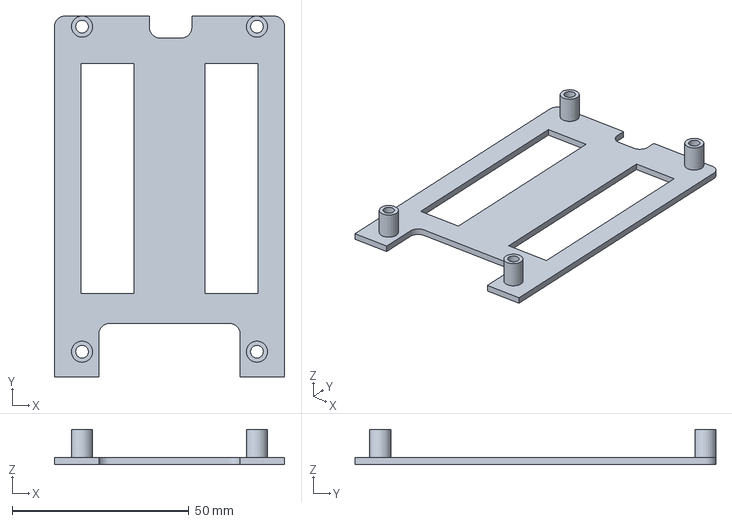
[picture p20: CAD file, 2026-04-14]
ESP32_V4/3d_print_files/ShutterTesterCase3dPrinted 3_5/TheShutterTester_tft_exp_frame_3_5.3mf
65.2 x 102.2 x 10.0 mm

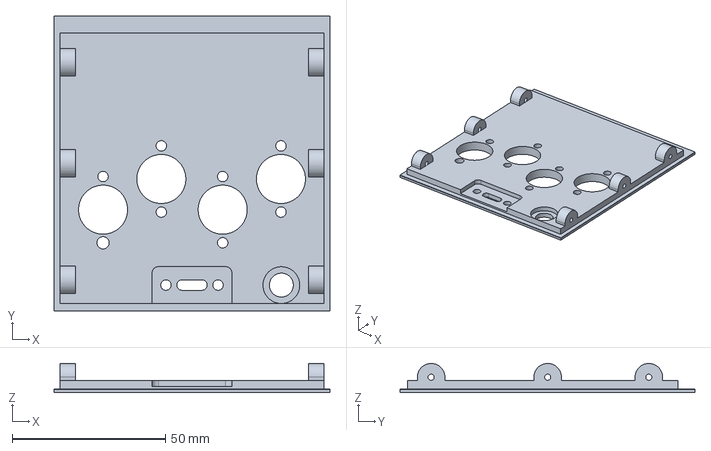
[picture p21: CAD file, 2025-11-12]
ESP32_V4/3d_print_files/ShutterTesterCase3dPrinted/TheShutterTesterRearFlushText.step
90.0 x 96.1 x 9.50 mm

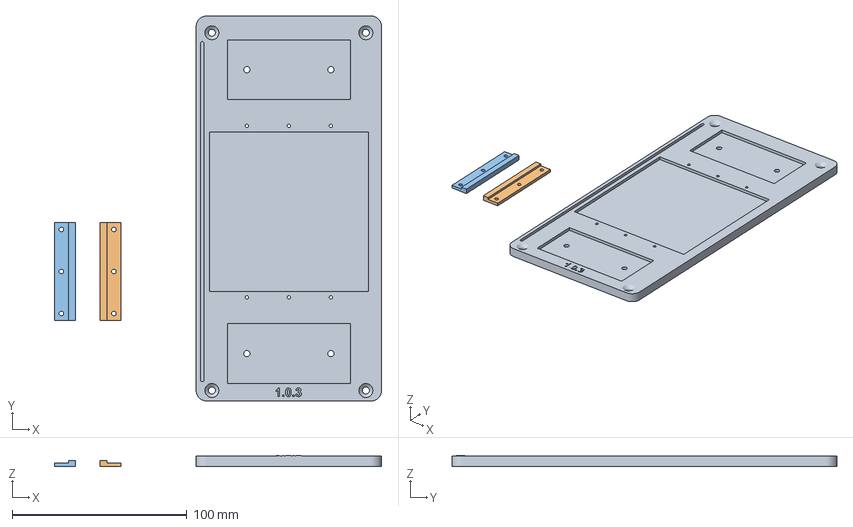
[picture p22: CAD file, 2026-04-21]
ESP32_V4/3d_print_files/ShutterTesterFrame/shutter_tester_base103.3mf
187.0 x 220.0 x 6.40 mm

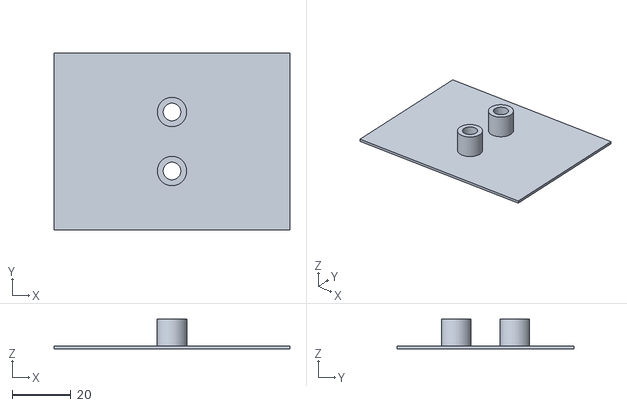
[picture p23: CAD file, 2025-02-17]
ESP32_V4/3d_print_files/Laser_holder_20mm v2.stl
80.0 x 60.0 x 10.0

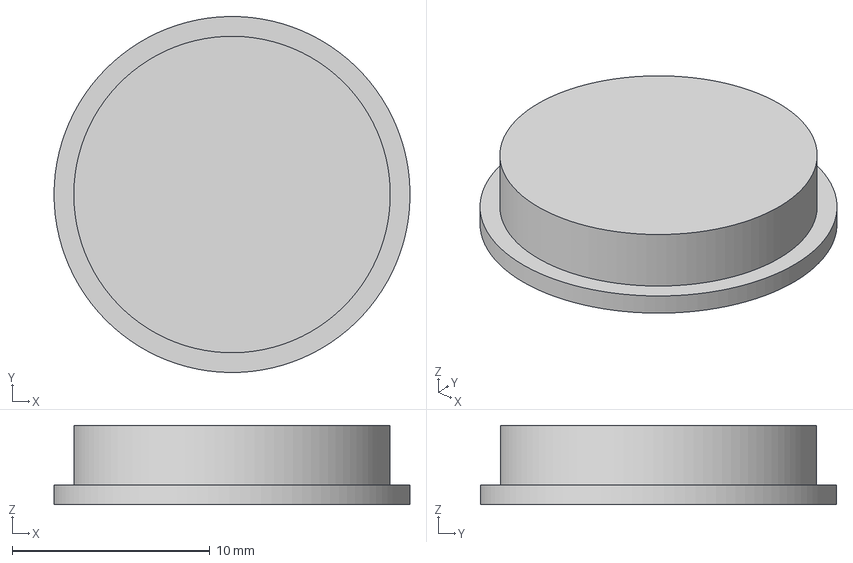
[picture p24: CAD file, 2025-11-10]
ESP32_V4/3d_print_files/ShutterTesterCase3dPrinted/TheShutterTesterBlank v1.3mf
18.0 x 18.0 x 4.00 mm

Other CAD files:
ESP32_V4/3d_print_files/ShutterTesterFrame/Shutter Tester Sensor Enclosure102.3mf
ESP32_V4/3d_print_files/Laser_holder_32mm v2.stl
ESP32_V4/3d_print_files/ShutterTesterCase3dPrinted/TheShutterTesterBox v15.3mf
ESP32_V4/3d_print_files/ShutterTesterFrame/Shutter Tester Laser Enclosure102.3mf
ESP32_V4/3d_print_files/ShutterTesterCase3dPrinted 3_5/TheShutterTester3_5_screen.f3d
ESP32_V4/3d_print_files/ShutterTesterCase3dPrinted/TheShutterTesterRear v6.3mf
ESP32_V4/3d_print_files/ShutterTesterCase3dPrinted/TheShutterTesterRearEngravedText v1.3mf
ESP32_V4/3d_print_files/camera_steady/camera_steady.f3d

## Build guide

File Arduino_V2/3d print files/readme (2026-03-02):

A 3d printed case is now available for the Arduino shutter tester.
All parts are shown on one plate, but it is best to print the parts seperately.

It is designed to use 13mm diameter buttons, a DIN socket (the socket could be negated and the wire just runn through the hole)
and a USB-C to USB-c chassis mount extension cable. 
Details of these parts can be found in the parts list document.

3d print files are also available for sensor and Laser enclosures.
These can be found in the ESP32 V4 folder.

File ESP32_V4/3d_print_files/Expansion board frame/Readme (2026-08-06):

The Shutter Tester Expansion Board Frame is an option when using the standard screw-terminal breakout board.

It slides onto the four tft mounting bolts.

Fix the breakout board to the frame using self tapping screws.

Note you will have to drill pilot holes into the frame.

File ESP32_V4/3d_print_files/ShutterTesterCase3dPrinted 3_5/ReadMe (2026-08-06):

The Shutter Tester is designed for the 4" screen specified in the parts document.

Other screens are NOT supported.

A few builders have not been able to get the specified 4" screen in their country and instead have used a smaller 3.5" screen 
which has the same tft and touch drivers and resolution as the 4" screen.

The file TheShutterTester3_5_screen.3mf in this folder is a slightly modified version of the orginal 4" print file called 'TheShutterTesterBox', 
with a smaller aperture to fit the smaller screen.

The file TheShutterTester_tft_exp_frame_3_5.3mf is a slightly modified version of the original, 
having the holes/standoffs moved to align with the fixing holes of the smaller tft screen,

The mounting hole spacing is 92mm x 49.5mm.

Other parts, (bottom & back) are the same as the 4" case and the print files will be found there

There are of course different 3.5" screens available. The 3d print files are made to fit one particular screen,
photos of which are in ther photos folder.

Note: The screen display is rotated 180 degress compared to the 4" screen, so when mounting, the connextion pins should be at the botom of the screen.

Note: IMPORTANT this 3.5" screen is NOT supported. Whilst my 3.5" screen worked fine, as has another builders, another screen was found to have black/white inverted. 
If this is a fault of the screen or a different varient is unknown.

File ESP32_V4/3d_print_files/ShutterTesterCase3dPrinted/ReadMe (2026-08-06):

These files are for printing a case for The Shutter Tester.
Print one TheShutterTesterBox and one ShutterTesterBottom.

There is a choice of three rear panels, either without legends,
with engraved legends 

or the third option using flush text of a different colour.
This file will require changing settings in your slicer, to print the 
text first, then change colour for printing the main rear part.

Finally there is a blanking piece for unused holes.

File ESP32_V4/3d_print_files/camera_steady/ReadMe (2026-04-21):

These 3d print files are for a steady, which fits onto the AliExpress 9cm x 9cm lifting table

The files were orginally made to fit the table I ordred, being 88mm x88mm.

21/04/2026 It was reported (thanks for the feedback) that a user's table, ordered from AliExpress, was 90mm x 90mm
thus the print file was slightly too small.

The file has been modified to fit a 90mm table.

If you have the smaller table (like me) there will be a little more play left/right
which is not an issue once the print is secured to the table top.

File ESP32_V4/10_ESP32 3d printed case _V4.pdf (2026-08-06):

GitHub repository where all documentation & code can be found. billbill100 (github.com) (https://github.com/billbill100)

ESP32 3d print case | V1.2 | 10/03/2026

To print the case.
There are four parts to print.
1) The main box (top sides & front).
2) Case bottom.
3) The rear panel, of which there are three options to choose from.
a) plain, which is the easiest to print.
b) the version with indented legends, labelling the sockets.
c) Third version has flat lettering. This requires a little more skill to print as the lettering needs to be selected and given a different colour to the box. Then the slicer needs setting so it prints all of the text first, followed by the rest of the rear panel.
4) The final part is the expansion board frame if using the screw-terminal expansion board from AliExpress, or
pcb spacer, if using the pcb expansion board.

There is also a blanking cap to print, for unused holes.

To Assemble. Four M3 X 25mm bolts go through the four holes in the front of the case.
On the inside, the TFT screen fits onto the bolts.

The expansion board frame (legs down) fit onto these bolts and it is all secured together with four washers and nuts.

The screw-terminal expansion board is mounted to the frame by drilling four small holes in the expansion frame, to match that of the expansion board itself, & attached with 2mm screws. The holes are not pre-drilled as expansion board hole positions can vary.

If using the pcb expansion board, the 3d printed pcb spacer is bolted to the lower holes on the pcb. M3 x 12MM bolts ideal, using the round holes. The elongated holes on the 3d printed spacer fit over the lower tft mounting bolts.

The 3d case is designed to be screwed together using 2mm self-tapping screws.

There is a lot of wiring to be connected (the pcb version negates some of this) and so it can be easier not to mount the expansion board until wiring is complete.

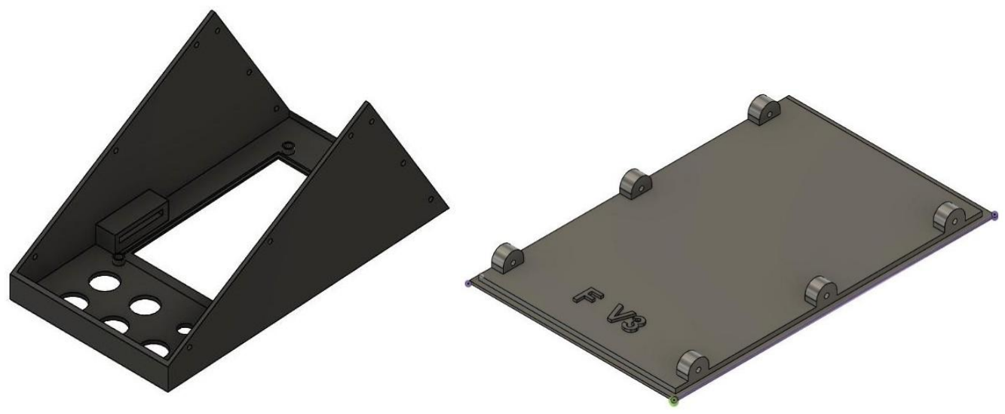
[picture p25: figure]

Main case | Rear

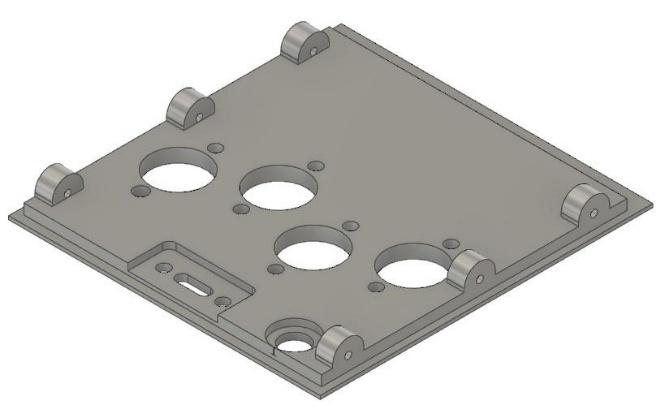
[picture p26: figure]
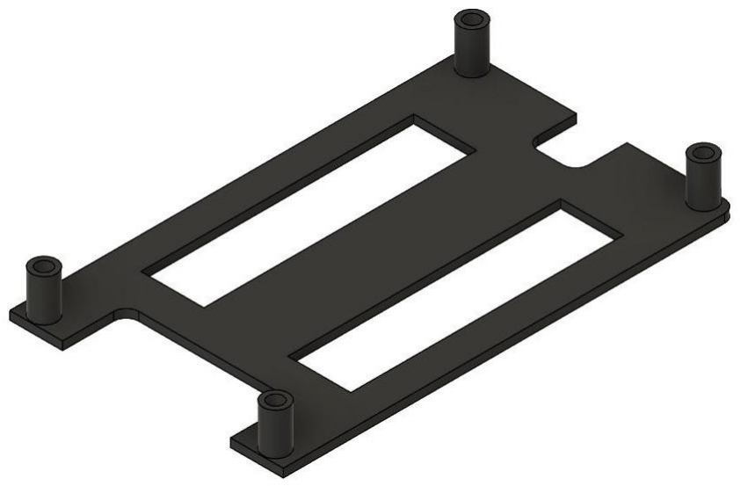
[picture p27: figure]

Back | Expansion Frame (if using screw-terminal expansion board)

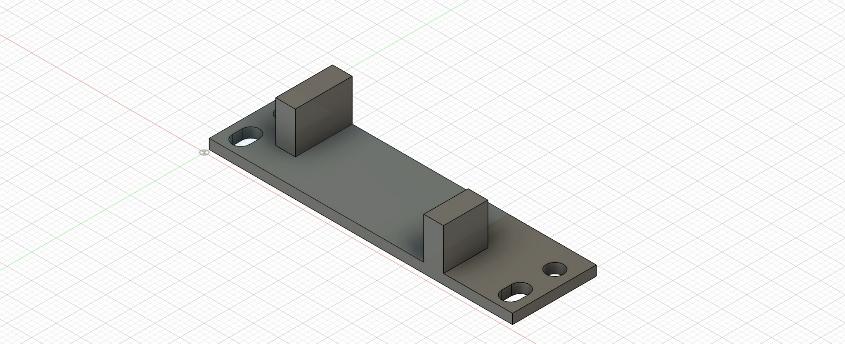
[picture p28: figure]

Pcb spacer (if using pcb expansion board)

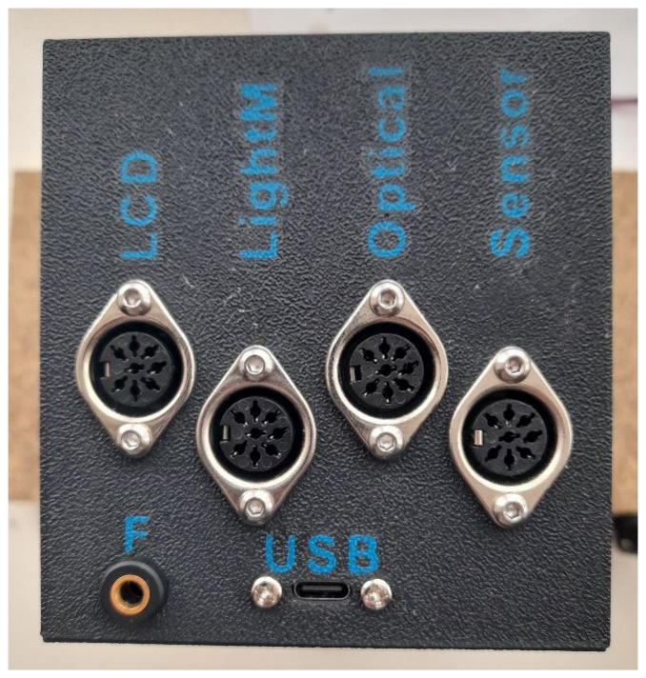
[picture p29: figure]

rear, showing option 3, with the colour printed legends.

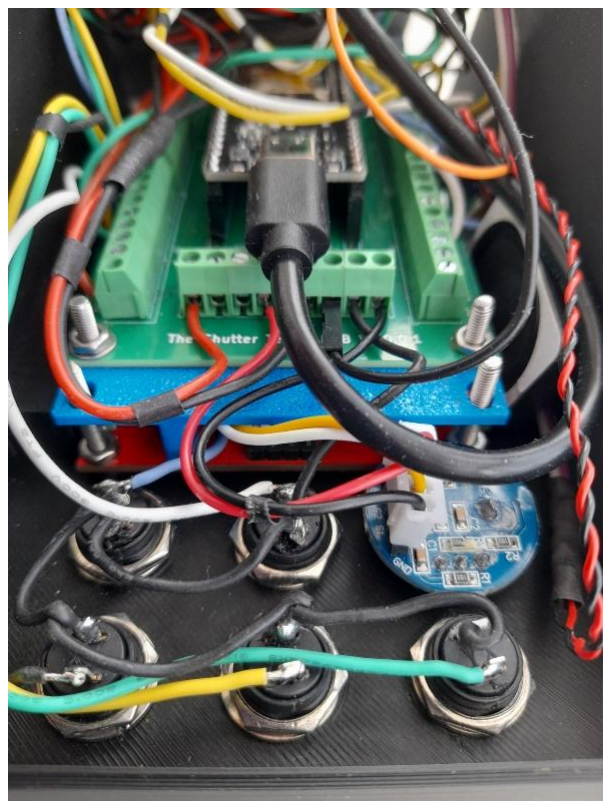
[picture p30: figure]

Pcb spacer, printed in blue.

Note – The case and enclosures are designed for the 13mm buttons, DIN sockets, USB cable and flash socket, as listed in the parts document.

Photos below showing the completed tester with sensor & Laser enclosure and base. Additional build guides are available for these.

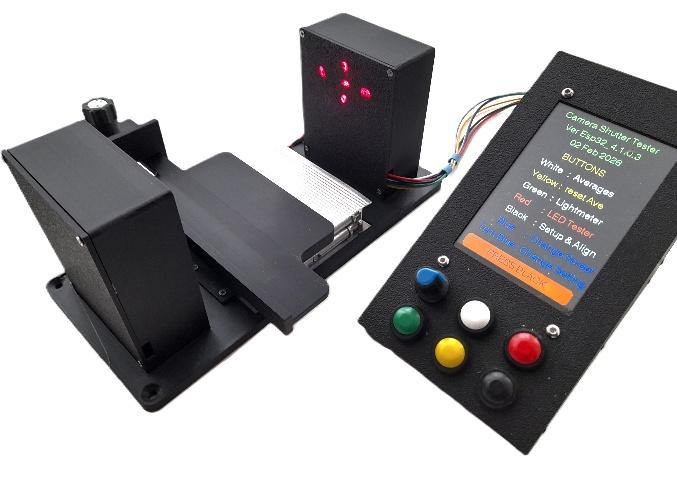
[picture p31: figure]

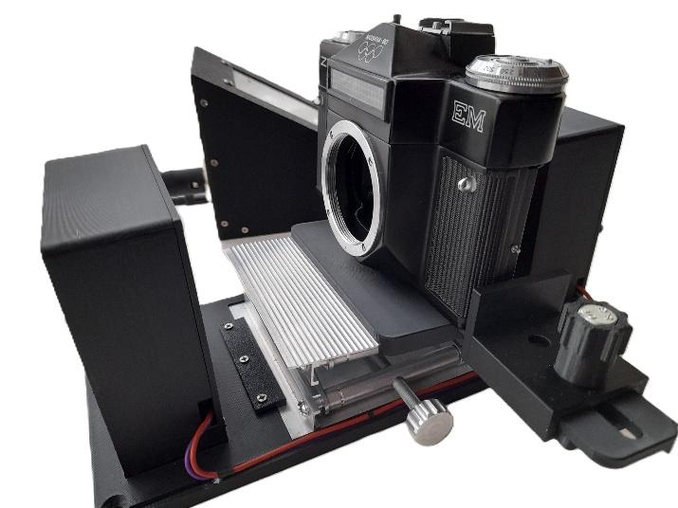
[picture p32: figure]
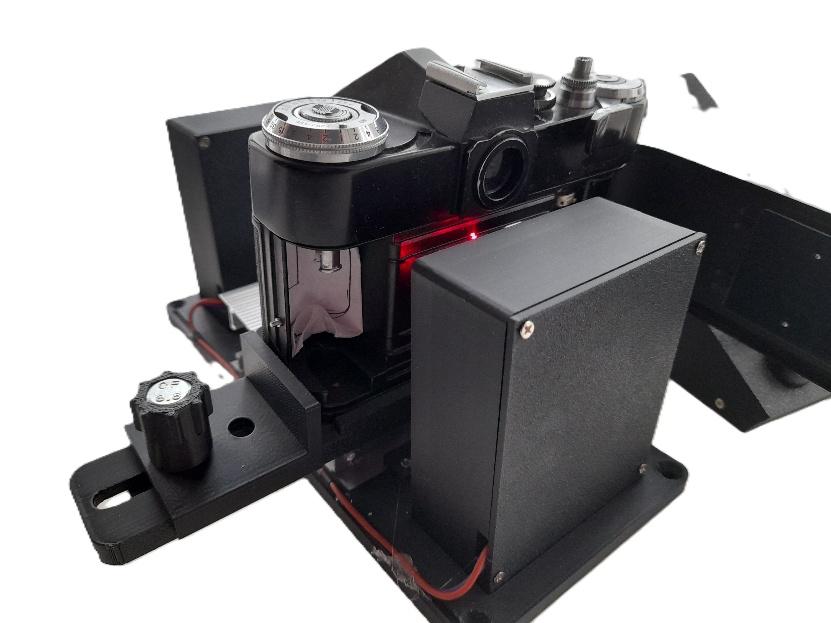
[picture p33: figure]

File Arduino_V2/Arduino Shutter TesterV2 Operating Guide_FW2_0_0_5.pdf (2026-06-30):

Doc V2.0.2 30-06-26

### Arduino Shutter Tester Version 2

Build a shutter tester for Focal Plane shutters - Cheap, Easy & it Works | Page 23 | Photrio.com Photography Forums (https://www.photrio.com/forum/threads/build-a-shutter-tester-for-focal-plane-shutters-cheap-easy-it-works.197756/page-23)

This document is for firmware 2.0.5 and later. For older firmware, refer to the previous Operating Guide.

First use after loading firmware

Assuming the build has been completed correctly and the firmware loaded, when the Shutter Tester is connected to the computer via the USB cable, The LCD should light and display text.

If the LCD lights, but no text can be seen, try adjusting the contrast screw on the back. As an initial setting, turn fully clockwise and then just a small amount back.

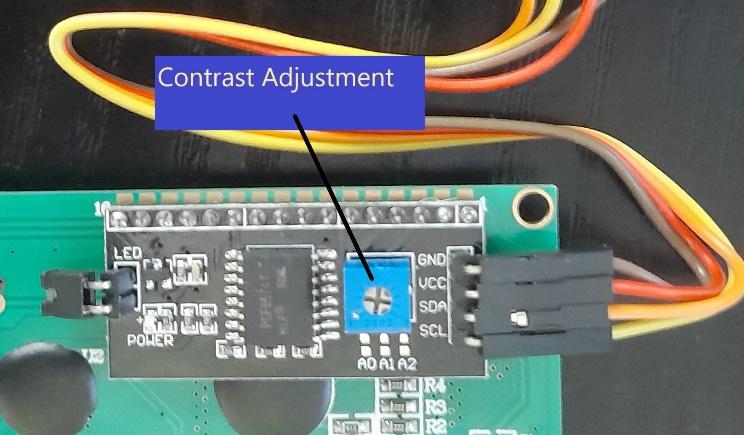
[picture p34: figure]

User Authentication.
The first time the Shutter Tester is operated, the LCD and PC screen will say ‘Auth Code’ and display a number. This number must be sent via private message to Niglyn. The quickest way is via the Photrio forum, link at the top of the page.

A user key will be sent by return and must be entered into the shutter Tester. This is only required once.

To enter the user key, press the Right Button. Each press increases the displayed number by 1.
Keeping the button pressed will rapidly increase the displayed number. A quick press will increase the number by 1.

When the supplied user key matches that displayed, press the Left Button.

Be careful not to overshoot the number, else you will need to continue to 9999 then keep pressing, as the number wraps round to 0.

Alternately, press the Left Button. The Shutter Tester will restart and you can try again.
Note each incorrect attempt will cause a greater delay before the pass key can be re-entered.

Once entered correctly, the screen will say ‘Correct’. After a short while the screen will blank & go dark. After some internal number crunching, the Shutter Tester will spring back into life.

Note Most output, (other than Laser Alignment Utility) is also sent to the PC screen using the Arduino IDE Serial Monitor, as described later in this document.

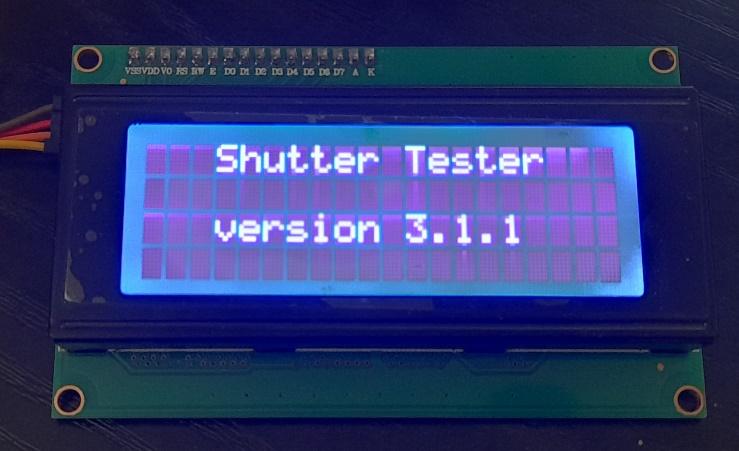
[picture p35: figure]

Splash Screen.

Laser Alignment Utility.

To enter the Alignment utility, when the splash screen has cleared and the normal testing screen appears, press the Left Button.

This utility will allow checking and aligning of the laser and receiver pairs by giving an indication on the LCD whether or not the sensor can see the laser beam.

When the laser is shining onto the receiver and the receiver can see the laser, the LCD will report ‘Seen’ When the laser is blocked, by a piece of card or your hand, the LCD will say ‘blocked’.

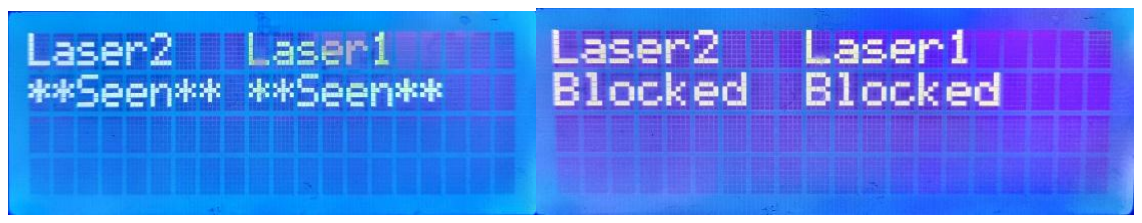
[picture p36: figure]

There are two different versions of the sensor, referred to as ‘original’ and ‘new’. Both look identical, so there is no way to tell by looking, which type they are. The only difference between the two is that one has an inverse output to the other. If the Laser Alignment Utility seems to be working backwards, it means you have the old type of sensor.

To change the sensor type, press the Right Button.

To exit the utility, press Left Button.

If there is no change at all to the LCD screen, then check all the wiring. Lasers should be shining Red and the LED on the receiver boards should be on. There is no protection from incorrect wiring or sensor orientation on the boards, so incorrect wiring will most likely result in a damaged board or sensor.

Important Note from around 2026 a faulty batch of sensor PCBs were made. On the board, there are two resisters. One reduces the current and feeds the LED. This is fine.
However, the ‘pull up’ resister, which gives low current feed to the Arduino, is missing a trace on the pcb.
This has the effect of making the sensors appear not to change state. Check the pcb to see if your board(s) have this fault.

Note: - You will probably find that the Laser barrel is not affixed to the pcb other than by its connecting wires. Adding a bit of hot-glue, or another suitable adhesive, will hold it in place.

To exit the utility, press ‘Reset Average’ button.

Note: - The Laser Alignment utility is only displayed on the LCD, no output is sent to the PC screen.

Normal Use

After the initial splash screen, the LCD will change to the testing Screen.

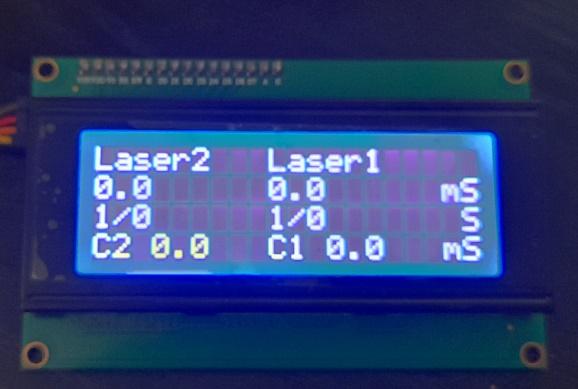
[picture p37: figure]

Testing screen

There are two columns. Each column will show the calculated exposure measurement from each of the laser and receiver pair.

The measured exposure is shown in milliseconds (0.001 of a second) one decimal place.

The fractional value is then shown below

The last value in each column C2 & C1 show the time Curtain1 and Curtain2 took to travel between the two sensors in milliseconds.

Each time the camera shutter is fired, the display will automatically update.

The letter ‘R’ will appear on the top right of the LCD (and ‘Ready…’ on the PC screen) when the Shutter Tester is ready for a new test. The sensors must be blocked, for this to happen.

If ‘B’ appears in the top right corner, it is indicating that shutter bounce has been detected.

Averages.

Pressing the Left Button will show the average of (up to) the last ten readings.

Pressing the Right Button will reset all the average readings. The last test result is displayed (but not recorded in the averages).

Press the Left Button to return to the testing screen.

Note: - Due to limitations of the Arduino memory, error checking is limited. So strange readings may occur, for example fingers waved across the lasers or a seriously badly behaving camera is being tested.
LED light, including computer monitors, can also be problematic if it is PWM controlled. The Shutter Tester may see this as sensor changes.

Computer Screen Display

More information can be displayed on the computer screen, than that of the LCD alone.
For this, a computer program called ‘Arduino IDE’ will be required. See separate document of how to instal this program.

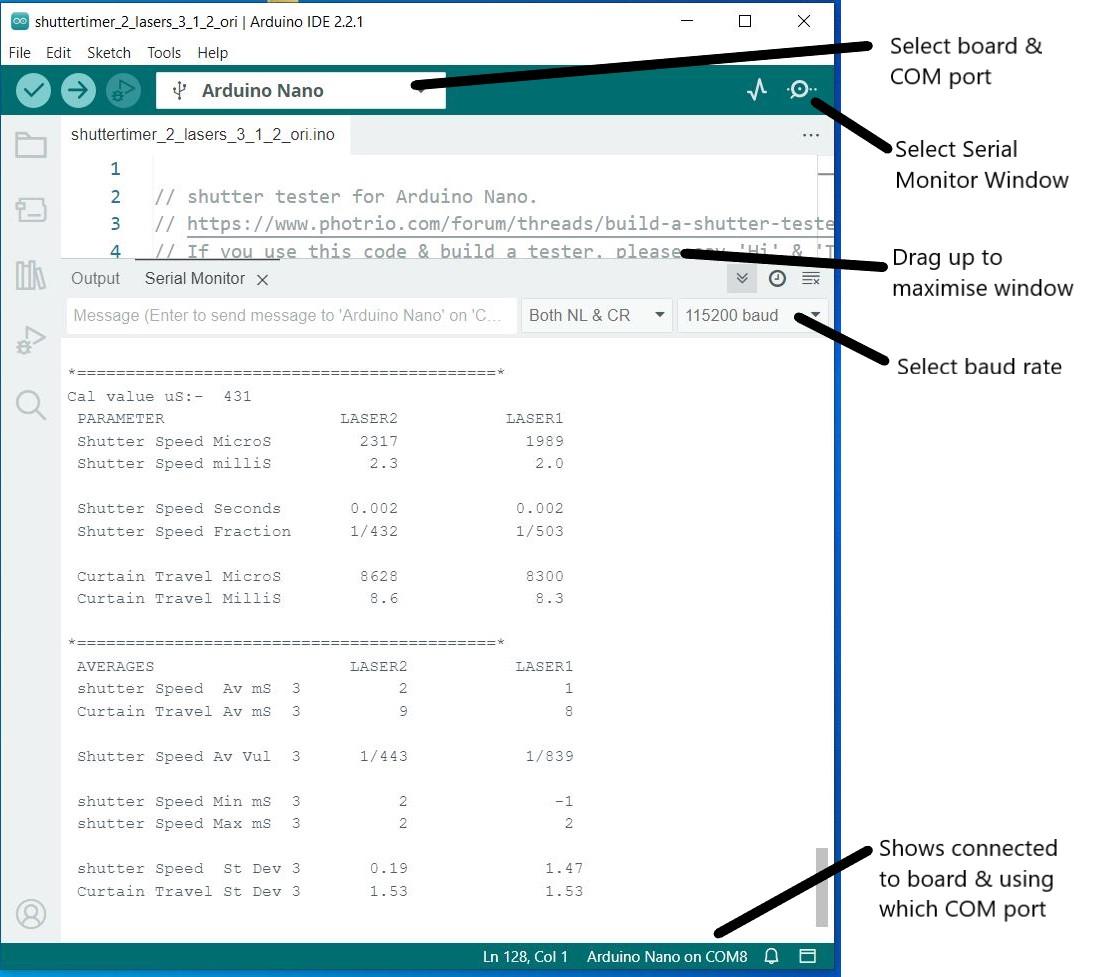
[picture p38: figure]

The display follows a similar format to that of the LCD, but with more information.

Shutter bounces will be shown as well as if flash sync has occurred at the given speed.

Averages are updated and displayed. The number of cumulative tests used to calculate the average are shown (in this picture, 3 can be seen).

A maximum of ten individual tests are used to calculate the average. After this, the oldest is lost from the calculation and the latest reading added.

As with the LCD, pressing the ‘Reset Average’ button will clear the historic data and new averages will be calculated using new test data.

V 2.0.1

Updated wording stating PC screen can also be used for authentication.

V2.0.2
Button functions changed
Button legends appear on the LCD
Ability to change sensor type added.

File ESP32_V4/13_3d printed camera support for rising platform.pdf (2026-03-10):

3d printed camera support for rising platform.

Ver 1.0 05 March 2026

The little rising platform (pictured below) available from AliExpress (detailed on the parts list document), is ideal for raising the camera to the correct height when using The Shutter Tester.

However, the platform is a little too small, so a larger top can be printed, which also has the advantage of locating the camera correctly in the left-right position.

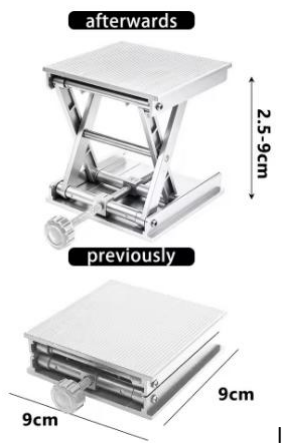
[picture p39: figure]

lifting table from AliExpress

The parts to be printed are shown below. The main platform should be printed with supports, to ensure the slot is formed correctly.
Other parts do not need supports. The parts are drawn all on one plate, but it is best to print each part separately.

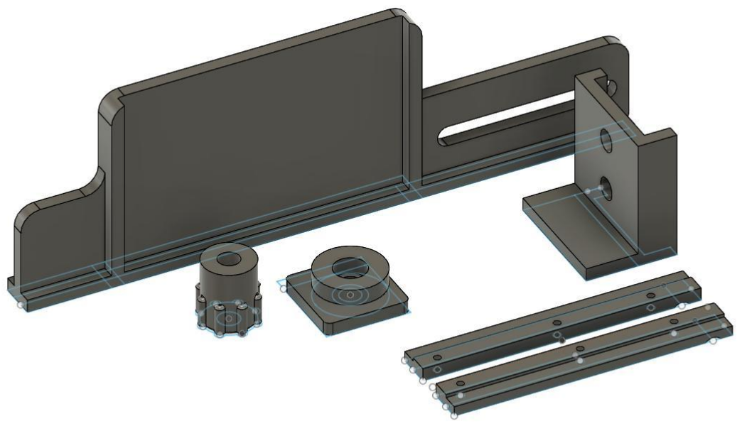
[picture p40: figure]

The parts are,
Main table,
sliding L piece,
hand adjuster (houses bolt)
captive nut plate
2 X clamps, to screw the table to the baseplate.

Additionally, one M5 X 35mm nut, bolt & washer, with 10mm head, will be required, screws to fix the platform to your baseboard and adhesive to glue the 3d printed part onto the platform.

After printing, the bolt is pushed into the hand adjuster and head pushed into the hex opening at the end. It is a tight fit. You may need to put the washer and nut on the thread and tighten the nut, to pull the head of the bolt into the hex cut-out.

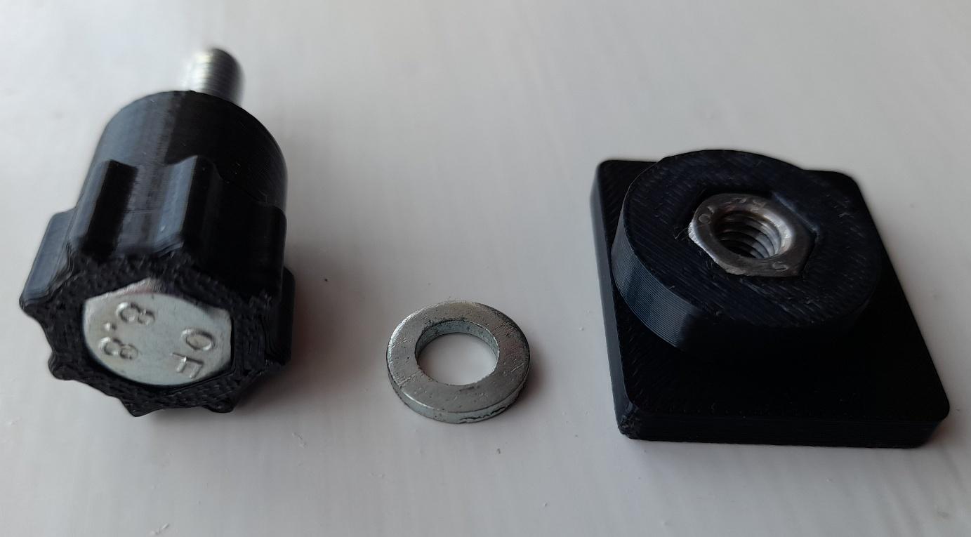
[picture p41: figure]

The nut is pushed into the hex shaped hole in the captive nut plate.
This is similarly a tight fit and may need the washer and bolt, to pull the nut in.

These two parts (with washer) are assembled with the L piece, to allow for adjustment to suit the camera width, as shown below.

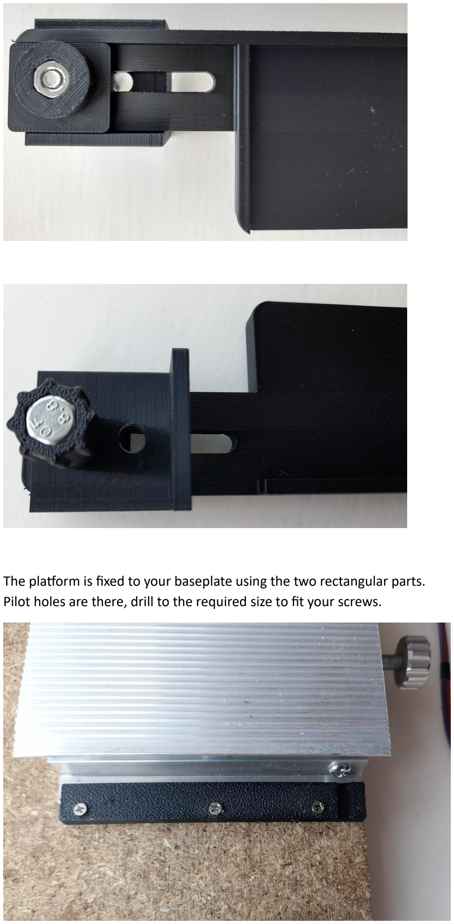
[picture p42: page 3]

The platform is fixed to your baseplate using the two rectangular parts. Pilot holes are there, drill to the required size to fit your screws.

The 3d printed assembly is best attached to the platform using a suitable adhesive.
If using screws, holes must be drilled & countersunk.
There is little space below the platform, so screws must be short, else they will foul the lifting mechanism.

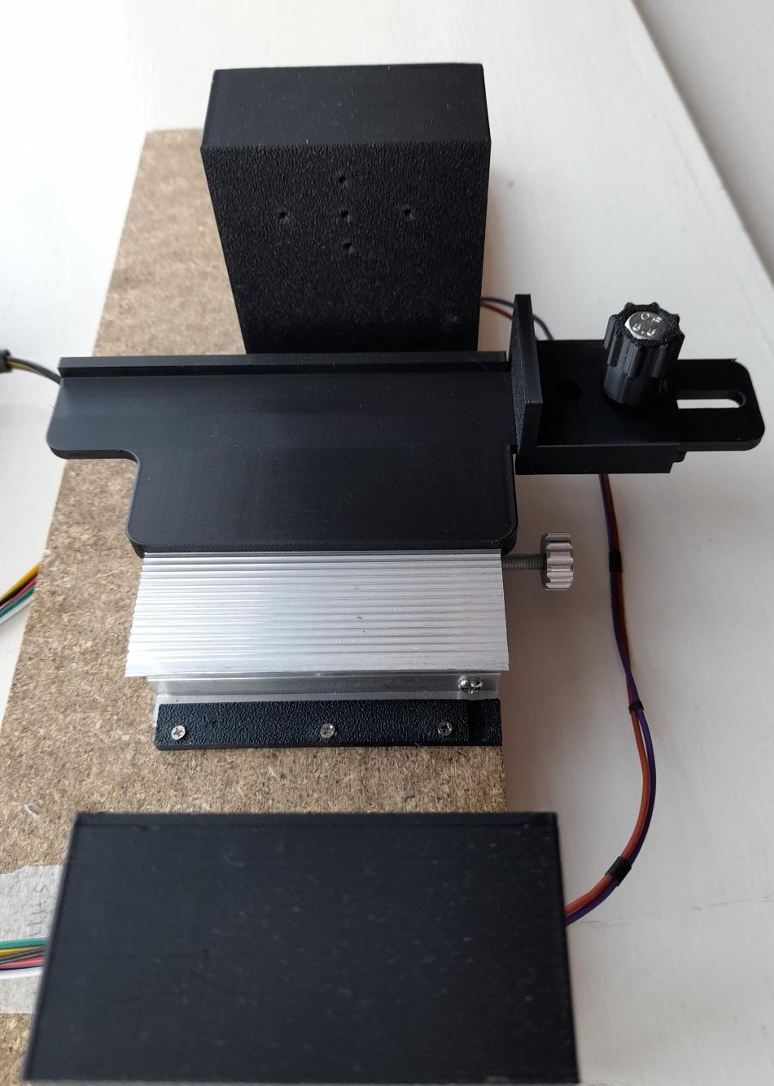
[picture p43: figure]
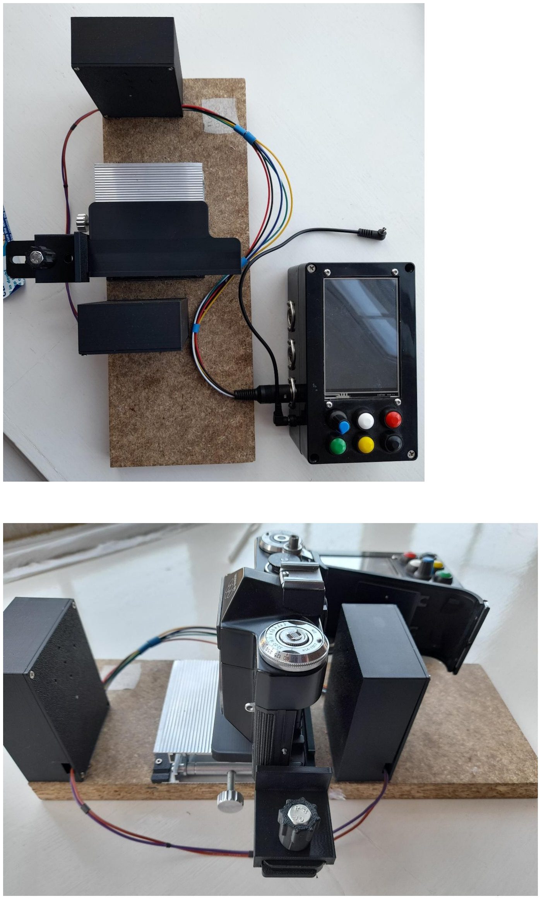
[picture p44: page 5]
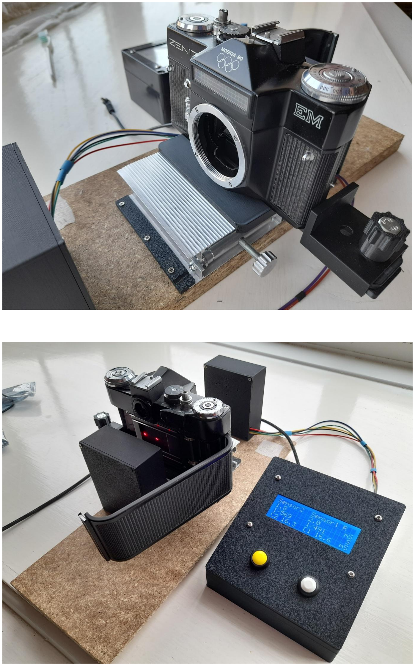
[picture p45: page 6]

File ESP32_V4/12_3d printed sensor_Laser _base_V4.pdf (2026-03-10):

GitHub repository where all documentation & code can be found. billbill100 (github.com) (https://github.com/billbill100)

## Sensor & Laser Enclosures & Base V1.2 10/03/2026

To print & assemble the sensor enclosure.
The sensor & Laser parts can be printed. Whilst each plate shows multiple parts, to group items together and reduce the number of 3d print files, it is best to print just one part at a time & remove from the build plate before printing the next.

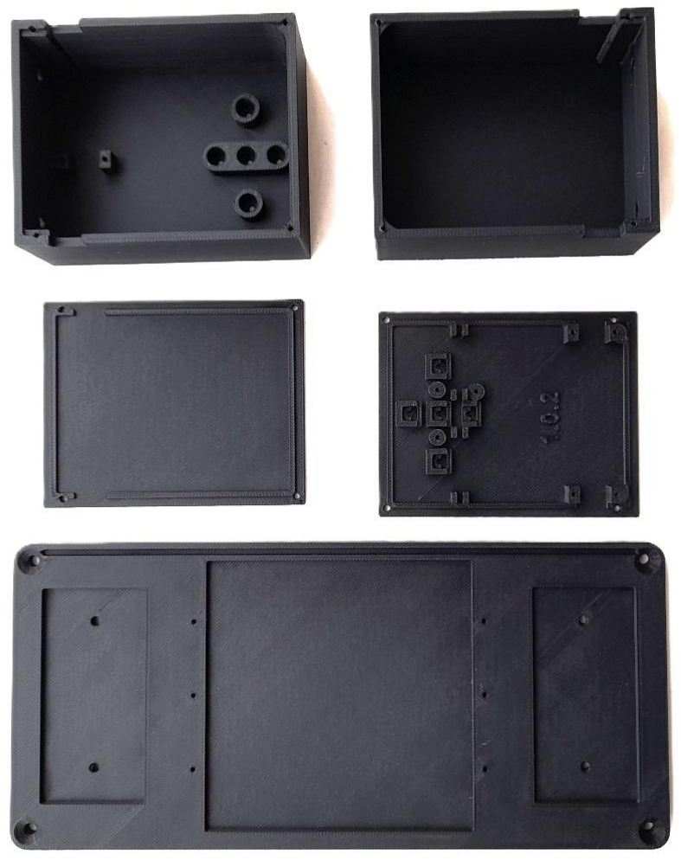
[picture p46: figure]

Photo shows sensor & Laser enclosures and base (not shown, cable clamps & Laser aligning tool)

Note: The 3d printed parts will accept placement of sensors and Lasers for horizontal vertical shutter testing. However this document describes only how to make a horizontal tester.

Make the sensor board
The sensors will not fit into the enclosure when mounted on the modules. So a new part is made using stripboard, as detailed below.

The stripboard is cut to fit in the box. Do not cut it to fit too tightly, a little play makes it easier to align. A junior hacksaw will cut the board.

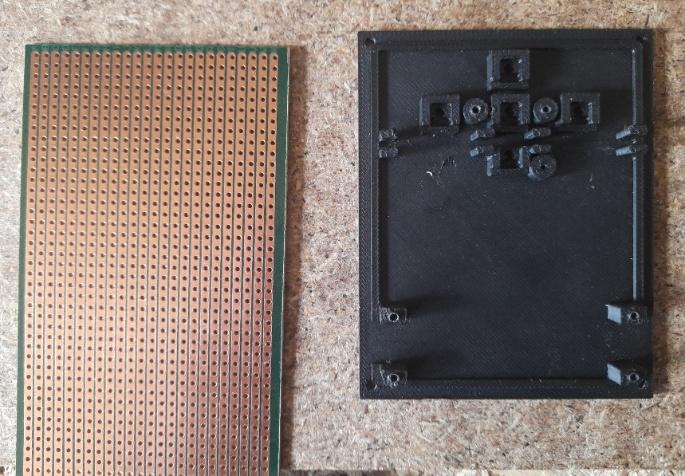
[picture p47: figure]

Stripboard and enclosure

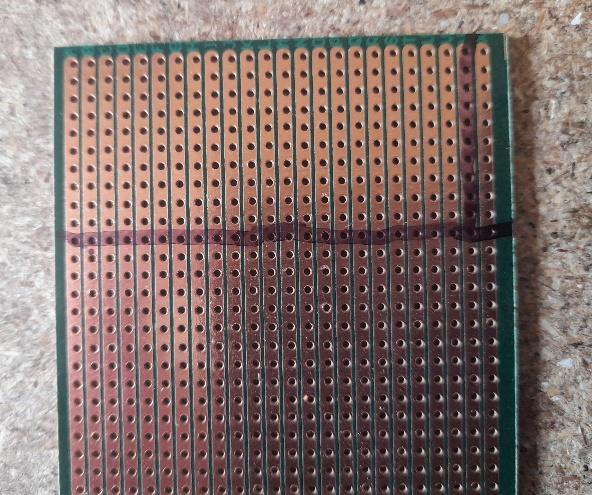
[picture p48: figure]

If using the board specified in the parts list, cut through the 11th line of holes then trim of 1 ½ holes from the edge. A junior hacksaw works well for this. The board is tough.

Trial fit the stripboard in the lid and then put into the box, to ensure it is not too long.

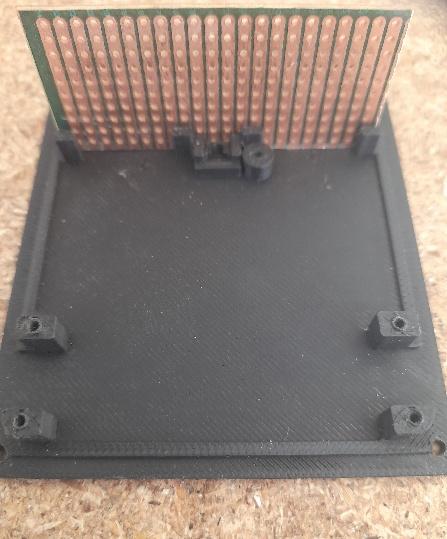
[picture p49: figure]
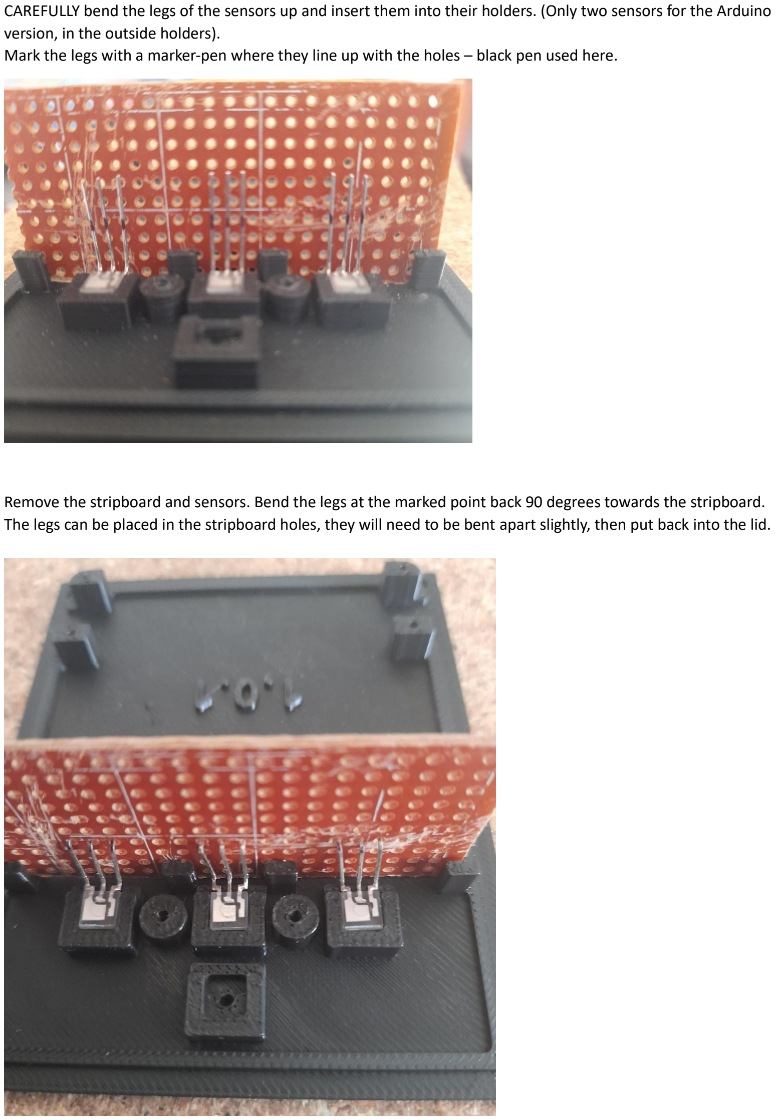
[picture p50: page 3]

CAREFULLY bend the legs of the sensors up and insert them into their holders. (Only two sensors for the Arduino version, in the outside holders).
Mark the legs with a marker-pen where they line up with the holes – black pen used here.

Remove the stripboard and sensors. Bend the legs at the marked point back 90 degrees towards the stripboard. The legs can be placed in the stripboard holes, they will need to be bent apart slightly, then put back into the lid.

Ensure the sensors are located correctly. By carefylly holding the sensors and turning the lid over, the sensor lens can be seen in the holes.

Fit the T shaped sensor holder and screw into place. (no photo of this step).

Carefully solder each of the sensor legs. Inspect the solder joints to ensure they have not bridged the copper strips. Using a multimeter on the Ohms scale, measure between each row of copper strips to ensure there are no short circuits.

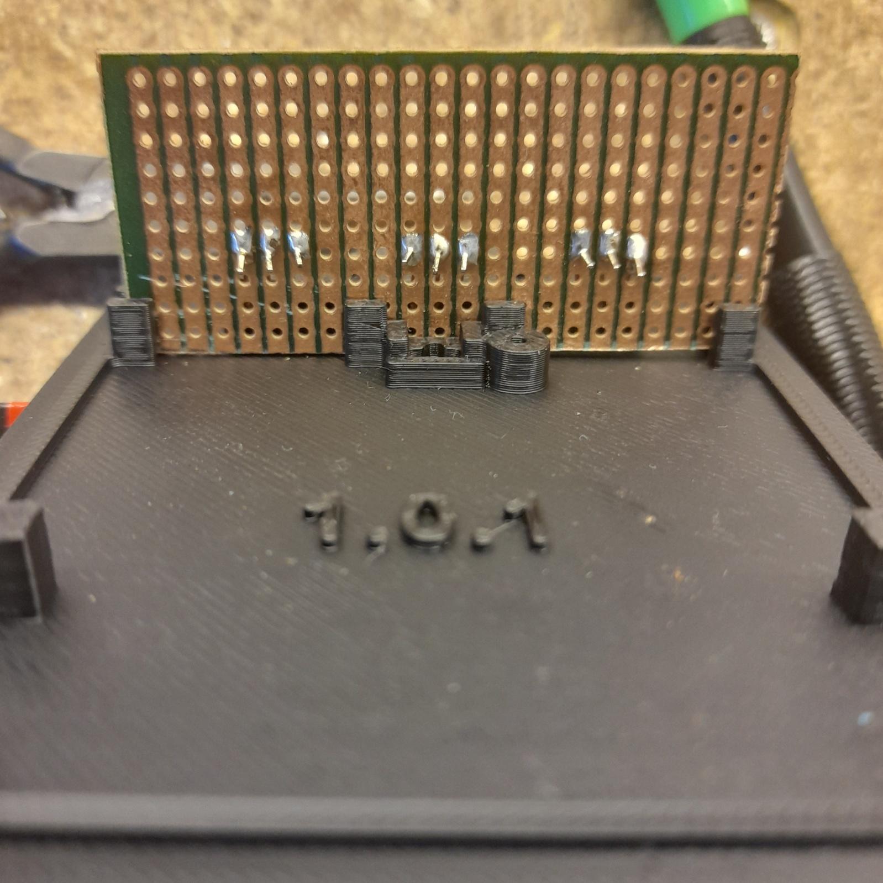
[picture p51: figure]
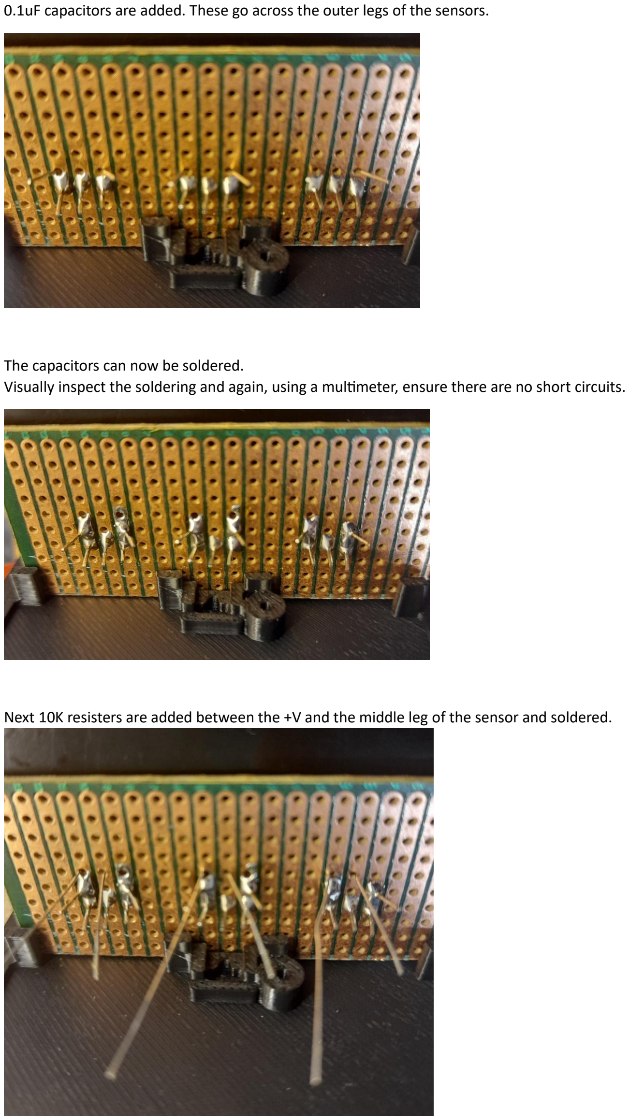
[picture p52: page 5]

0.1uF capacitors are added. These go across the outer legs of the sensors.

The capacitors can now be soldered.
Visually inspect the soldering and again, using a multimeter, ensure there are no short circuits.

Next 10K resisters are added between the +V and the middle leg of the sensor and soldered.

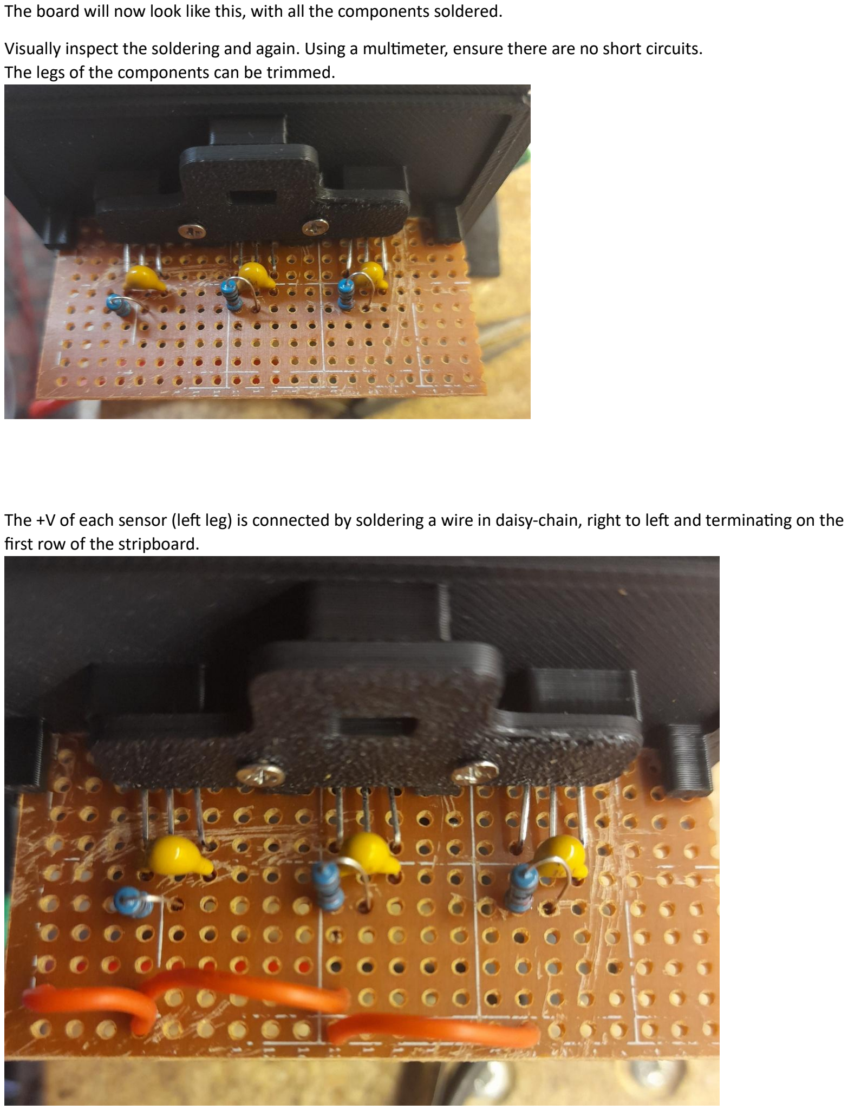
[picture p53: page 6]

The board will now look like this, with all the components soldered.

Visually inspect the soldering and again. Using a multimeter, ensure there are no short circuits. The legs of the components can be trimmed.

The +V of each sensor (left leg) is connected by soldering a wire in daisy-chain, right to left and terminating on the first row of the stripboard.

The 0V of each sensor (right leg) is connected by soldering a wire in daisy-chain, right to left and terminating on the second row of the stripboard.

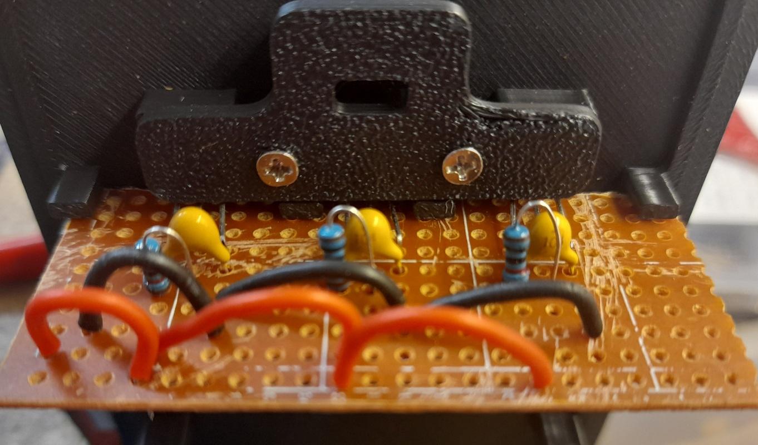
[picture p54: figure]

+V & 0V wires from the screw terminal board are now soldered to the respective copper strip.
Note: - on the prototype it was thought a good idea to have wires connected on the bottom, as shown here.
It does work but is more difficult than if they come from above.
It might be better to have the wires entering from above and cutting a corner off the stripboard, to allow the wires through and into the bottom of the box, to exit.

The +V and 0V for the Lasers can also be connected here.

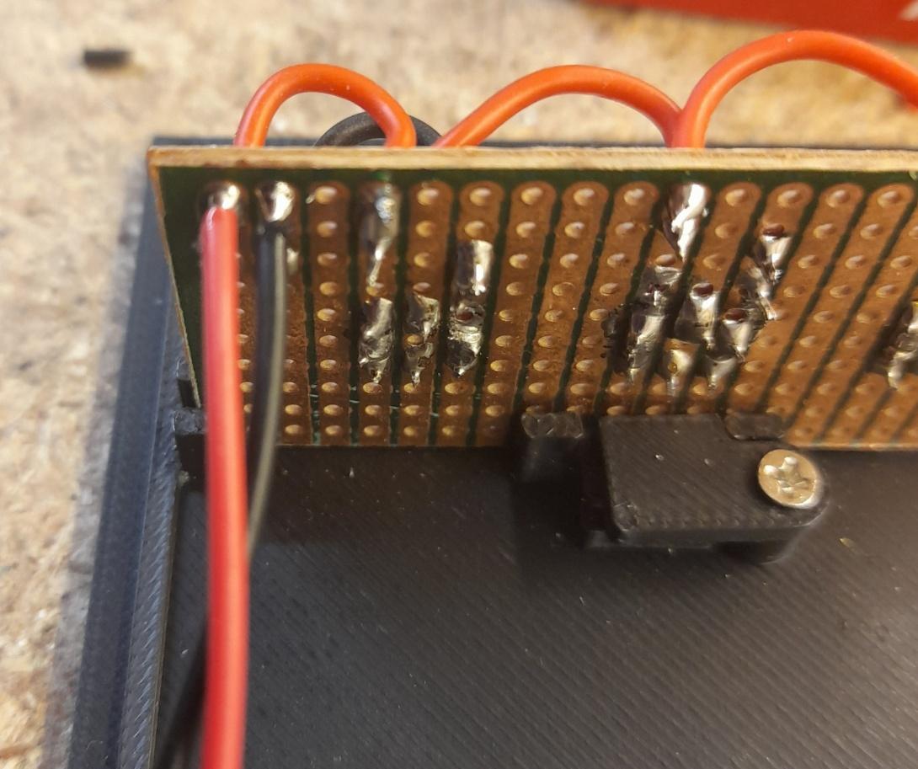
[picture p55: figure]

The three wires for the sensors are now soldered to the centre leg of each sensor.

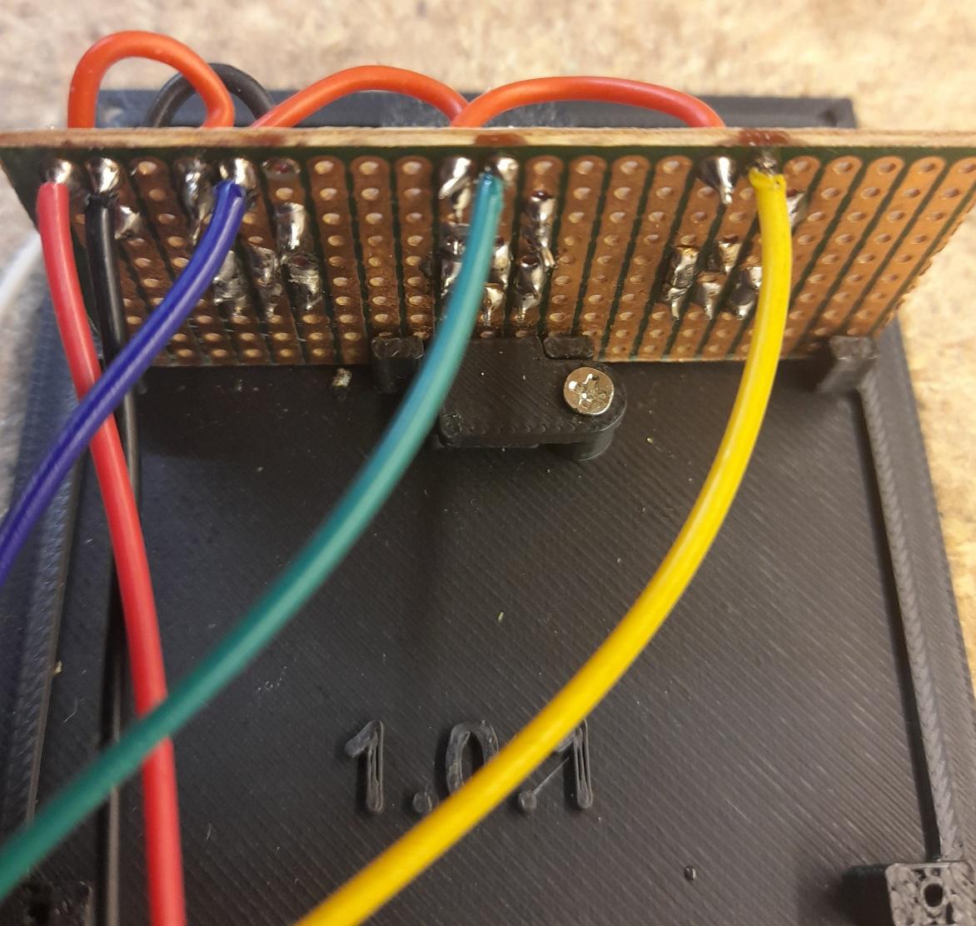
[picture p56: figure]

Wires are now secured under the clamps.
The wires can exit either side of the box, depending on user preference.
(White wire shown is not connected. Brown & purple wire on the right feeds the Lasers.)

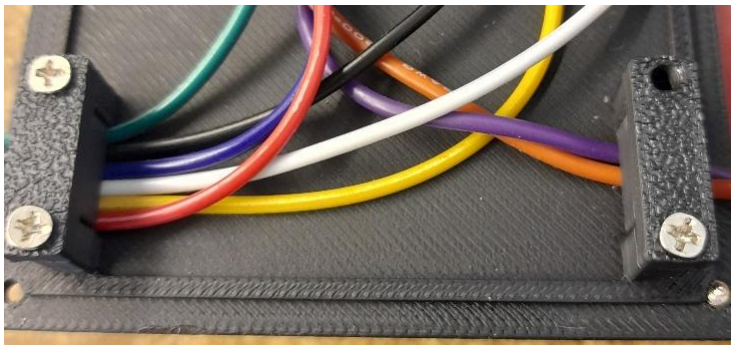
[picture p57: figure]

With a multimeter set on the Ohms scale. Measure between the +V and 0V wires. Ensure there is not a short circuit. Now measure between the +V wire and each of the sensor output wires. Ensure there are no shorts. The meter should show 10K Ohm.
If voltage is applied directly into the microcontroller pin, without the resister, it WILL destroy the board.

To mount the enclosures.
The Laser encosure and base should be printed.

The sensor enclosure is mounted to the base first, using M3 X 12mm bolts, nuts & washers. The base has a slot for running the wires from the sensor enclosure to the Laser enclosure. The slot can be on the left or right, depending on how the builder chooses.
Ensure the enclosure is pushed fully back within the mounting recess, before tightening the bolts, to leave space for the lid.

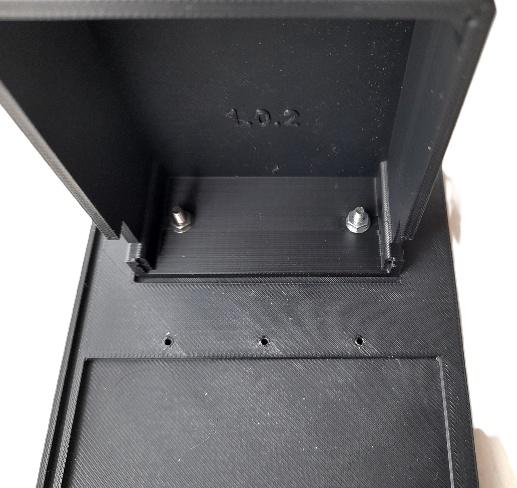
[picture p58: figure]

The lid, containing the sensors can now be fitted, using 2mm x 6mm screws. Note the wires for the Laser box running in the slot to the left.

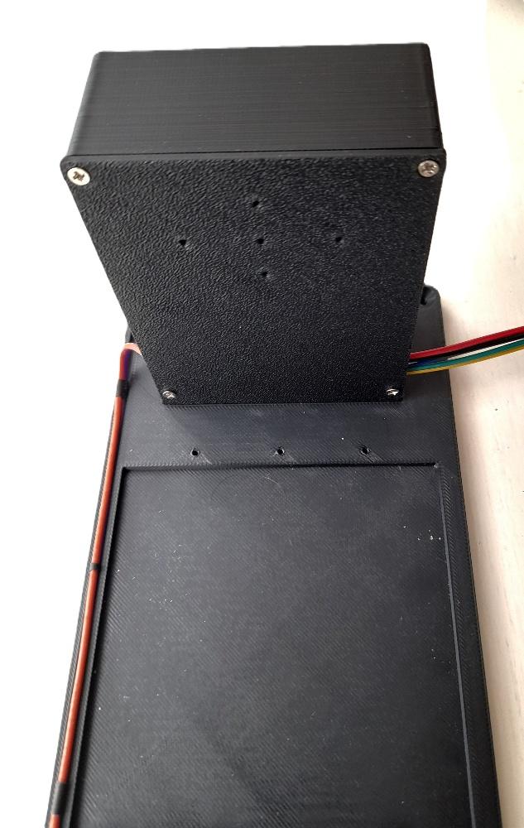
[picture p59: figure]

The lifting table can now be fitted. The adjusting knob should be on the left, at the bottom. Two 3d printed clamps fit either side of the table and are fixed with M2 x 8mm screws.

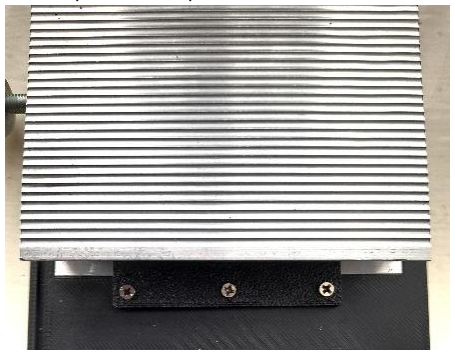
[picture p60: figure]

The Laser enclosure is fitted next, using M3 X 12mm nuts, bolts and washers.
Note the orientation of the box. Before tightening the bolts, ensure the box is pushed fully back within the recess, to allow space for the lid.

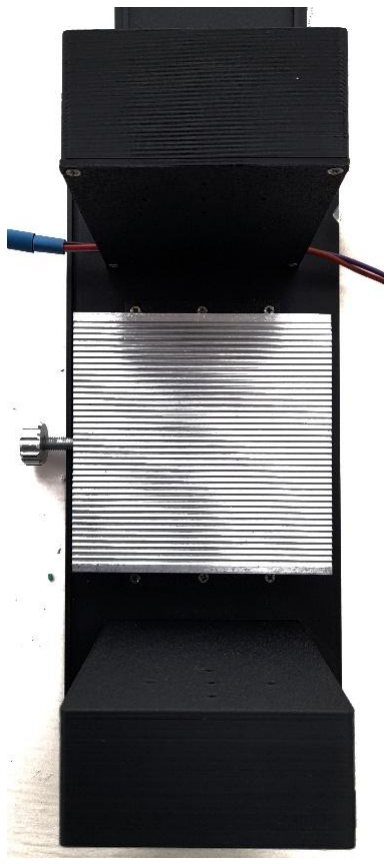
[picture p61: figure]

To assemble & align the Lasers.

The wires soldered onto the Lasers are very thin and delicate. Adding some hot-glue on the solder-joint and onto the insulation will help add strength & prevent them breaking during the next step.

The ends of the Laser +V wires (Red) can be soldered together and connected to the +3 or +5V supply. Do the same with the 0V wires (Blue). Ensure all joints are insulated.

The unit mut now be powered, to illuminate the Lasers.

DO NOT directly look into the Laser or point it your or anybody’s eyes.

The Lasers can be focussed, by turning the collar on the end. However, do not focus to a pin-point, the Laser must cover at least the area of the sensor hole. Making the beam too narrow will make alignment very difficult.

Each Laser needs adjusting to point at the corresponding sensor.
The mounting frame can be turned on-end, so the Laser points down. This makes alignment easier.

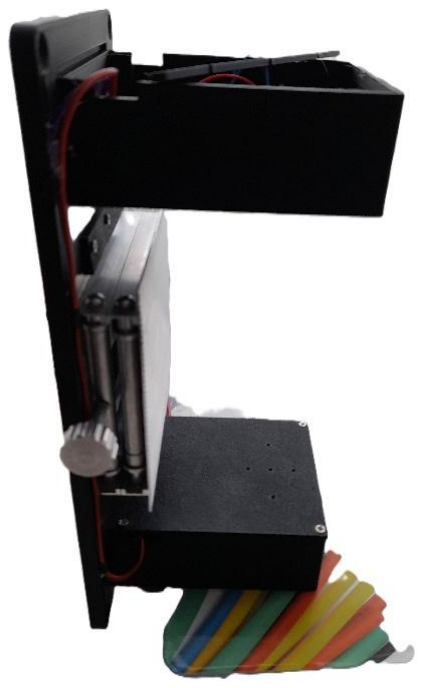
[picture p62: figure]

Hot-glue is used to hold the Laser in place.
The adjusting tool, pictured below is used to move the wires, which moves the Laser and then hold them in the correct position whilst the glue cools. A small weight can be added to the tool, if it will not stay in position.
Once the glue has cooled, additional hot-glue is added around the Laser.

Do this to each Laser in turn. Patience is required here, to allow the glue to fully cool, before moving onto the next Laser.

Note the photo shows the cables clamped, but do not fit the clamp this until all Lasers are aligned.

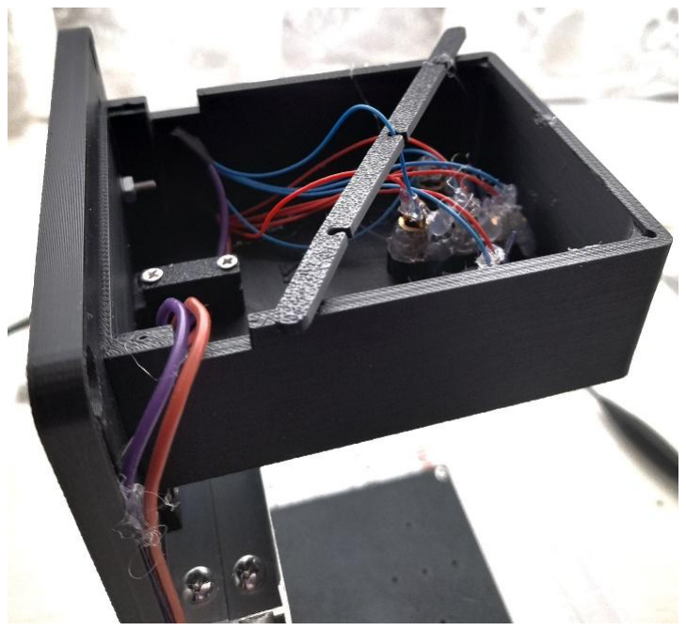
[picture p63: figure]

The rear cover can be screwed to the Laser box and this completes assembly.

A further document describes how to print and assemble the camera steady for the adjustable table.

Photos below showing the completed The Shutter Tester.

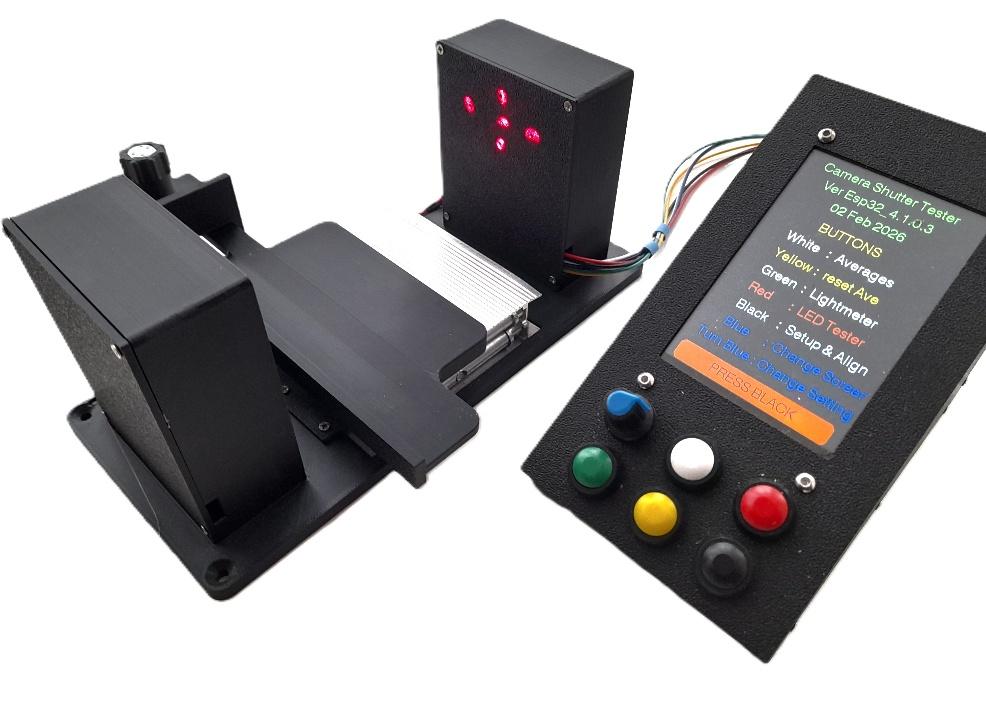
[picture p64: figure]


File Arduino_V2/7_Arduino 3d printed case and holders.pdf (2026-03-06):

## Arduino 3d print case and Sensor & Laser Enclosures V1.0 03/03/2026


GitHub repository where all documentation & code can be found. billbill100 (github.com) (https://github.com/billbill100)

To print the case.
There are four parts to print.
1) The main case (one part front & sides).
2) Case bottom.
3) Mounting plate for screw-terminal board.
4) washer

To Assemble. Two M3 X 25mm bolts go through the two top holes in the front of the case.
The LCD is then put inside the box, with the bolts going through the top two holes and secured with washers and nuts. Do not fully tighten.

Two more bolts and board holder added. Note the small hole is slightly offset to the left.


The screw-terminal board is added, with washers and nuts put on the remaining two bolts. All nuts & bolts can be tightened.
The 3d printed washer and a 2mm screw is used though the second hole of the expansion board.

Sockets & buttons are added and the wiring completed.

To print & assemble the sensor enclosure.

Please refer to the ESP32 ‘Print a case sensor & Laser enclosure’ document, found in the ESP32 folder on Github for details of these parts. They are identical other than the Arduino using two, rather than three sensors & Lasers.

Photos showing the sensor & Laser enclosure, with The shutter Tester case.
Also shown is the lifting platform with 3d printed cameras steady top.


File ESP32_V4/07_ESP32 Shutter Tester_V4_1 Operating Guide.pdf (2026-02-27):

I would really be grateful if you start to build the Shutter, that you go to the Photrio thread and say hi. Also please post photos of your completed tester.
Build a shutter tester for Focal Plane shutters - Cheap, Easy & it Works | Page 18 | Photrio.com Photography
Forums (https://www.photrio.com/forum/threads/build-a-shutter-tester-for-focal-plane-shutters-cheap-easy-it-works.197756/page-18)
Please refer to Photrio for further build help | Doc Ver 1.1
ESP32 Shutter Tester Operating Guide V4 | 27/02/2026

## (Firmware 4_1_0_0 onwards)

### First use after loading firmware

Assuming the build has been completed correctly and the firmware loaded, when the Shutter Tester is connected to the computer via the USB cable, TFT & LCD should light & there will be output to the pc monitor.

Please note, some of the photos are of previous firmware versions, so will not look identical to your tester.

Note on LCD
The LCD is not required for V4. Some users may have it from V3, or would like to add it anyway.
If the LCD lights, but no text can be seen, try adjusting the contrast screw on the back. As an initial setting, turn fully clockwise and then just a small amount back.


Step 1 is to test the encoder, which is the Blue Button. A screen as shown as in the pictures below, will appear on first use.
Turning the Blue Button will increase or decrease the value between 0-9999. Pushing the Blue Button will increase the button count from 1-10. (Pushing again returns to 0).

Following the on-screen instructions, press the encoder to show 10 and turn the encoder to show 40.


TFT showing encoder test.


LCD showing encoder test.


PC screen showing encoder test.

The screen will now change asking the user to wait, whilst a stability test is carried out. This ensures the encoder is not receiving errant input, from poor connections, for example. If all is well, the screens will change for step 2.

If the encoder test fails, The Shutter Tester will restart.

(photo of TFT to follow)


LCD showing encoder test passed.

PC screen showing encoder test passed.

Step 2 is to input the user-key. This is supplied free of charge upon request. Make a note of it, in case you ever perform a factory reset. For the key, post a request on the Photrio thread. Link at the top of this document.

Following the on-screen prompts, turn the encoder to show the user key value. Then press the encoder.
If correct, the Shutter Tester will restart.


TFT showing user key input screen.

LCD showing user key input screen.

PC showing user key input screen.


TFT showing user has input correct user key.

LCD showing user has input correct user key.

PC showing user has input correct user key.

If the user key has been entered correctly, ‘Correct! Will be displayed’ and the Shutter Tester will restart in normal operation mode.

Note: - Sometimes a firmware upgrade will require the Shutter Tester is reset to default factory settings, so ensure you keep a note of your user-key.

Normal use.

An initial splash screen is shown on TFT, LCD & PC screen. The LED Matrix will display firmware version.

This is displayed for a set period, before changing to the Testing Screen.
Note pressing the Black Button or Touching the screen will jump straight to the Testing Screen.


TFT splash screen.


PC splash screen.


LCD splash screen, due to size limitation only subset of info can be displayed.

### Alignment & Setup Utility

Pressing the Black Button will take you to the Setup & Alignment Utility. This is the first screen to go to when initially using the Shutter Tester.

The TFT, LCD & PC screen will show the current settings.

To select a setting, press the Blue Button. (Or touch the setting, if touch enabled)
On the TFT screen, a red marker will appear next to ‘Screen/Log’. Indicating this is the setting to be changed. On each press of the Blue Button, the red marker will move to the next menu item, to select it.

The lower line of the LCD will change, showing which setting is being changed.

The PC screen will give a text prompt.

To change a setting, press the Blue Button (Or touch the right side of ter screen, if touch enabled) Each of the settings are described below: -


TFT showing Settings & Alignment screen.

PC screen showing Settings & Alignment screen.

LCD showing Settings & Alignment screen.

Screen/log – This allows the user to set the data logging functions.
‘Screen’ will send test data to the PC screen (using a suitable serial monitor) in a humanised display format. ‘ScreenSD’ output is sent as above and to the SD card in csv format.
‘USB’ will send test data to the USB port as a csv file. Note the humanised PC screen cannot be used at the same time. ‘USB&SD’ will send test data in csv format to the USB port and SD card. Note the humanised PC screen cannot be used at the same time.

Sensor Type. There are two different versions of the sensor, referred to as ‘original’ and ‘new’. Both look identical, so there is no way to tell by looking, which type they are. The only difference between the two is that one has an inverse output to the other. If the Laser Alignment Utility seems to be working backwards, it means you have the other type of sensor.

Sensor Space This is the distance in millimetres between the two sensors, measured centre to centre. The standard is usually 32mm for horizontal and 20mm for vertical shutters.

Shutter Type Focal Plane, Leaf, or single sensor (Sensor no. 1 is used for single sensor readings).

Button Legend Shows the initial splash screen detailing Button use.

Text Colour Allows the default TFT text colour of Green to be changed.

To exit the utility, press Black Button (or touch the screen at the bottom).

A Default Settings Reset can be performed by pressing the Red Button and turning the Blue knob when in the Alignment & setup utility. Note this resets all settings to default. Your User Key is retained, so re-authentication is not required.

Sensor State is shown at the the bottom of the TFT screen, the state of each sensor is shown (Blocked or Seen) This is to allow the sensors and Lasers to be correctly aligned. If the legends are working in reverse, then change the sensor type setting as detailed above.

flicker warning will be displayed if interference is being detected by the sensors. The most common cause for this is LED lighting (including computer screens) that use PWM to control brightness. It can also be caused by electrical interference being picked up on the wiring to the sensors.

Touch Functionality.
Firmware 4.1.03 onwards – touching the parameter will select it directly.

Touching the right side of the screen will toggle though the selected parameter options, the same as rotating the Blue Button

Touching the bottom of the screen will return to the main testing screen. Same as pressing the Black Button.

(Previous firmware versions, touching the left side of the screen will scroll down the parameter list, the same as pressing the Blue Button).

Testing screen. (Detailed)..

TFT The testing screen of the TFT is arranged into four columns. The first column describes the measurement and the next three columns show the readings, one from each sensor. 2, M, 1.


TFT showing completed test (note old firmware shown).

Shutter SpeeduS | calculated reading from each sensor in microseconds
Shutter SpeedmS | calculated reading from each sensor in milliseconds
Shutter Speed S | calculated reading from each sensor in seconds
Shutter Speed 1/ | calculated reading from each sensor in milliseconds
Dev from Centre | calculated deviation from centre sensor in decimal stops
Dev from Centre | calculated deviation from centre sensor in 1/3 stops
Curtain Bounce | Number of times the curtain bounced on closure.
Curtain 1 Travel | Curtain1 travel time from right to centre (S1) and from centre to left (S2)
Curtain 2 Travel | Curtain2 travel time from right to centre (S1) and from centre to left (S2)

_____________________________________________

Shutter Nearest | Nearest standard shutter speed to actual reading
Dev from Nearest | Nearest Deviation from nearest standard shutter speed in decimal stops
Dev from Nearest | Nearest Deviation from nearest standard shutter speed in 1/3 stops

Below the detailed results, is the adjunct area, where errors and warnings will be displayed

If connection to the camera flash socket was detected, analysis of the flash will be shown.

The word ‘Ready will also appear here, in white, when the Shutter Tester is able to perform another test.

At the bottom of the screen, the main readings repeated, but in a larger typeface and the total curtain travel times.

Readings that are out of specification will be highlighted in Yellow or Red, on the TFT screen depending on how far off they are.

Autoscaling
The mS and Seconds display on the two TFT large typeface screens & LCD auto-scale, to allow better granularity.

Diagnostics
The Shutter Tester carries out verification and fault diagnostics of the shutter cycle results.
This includes full flash synchronisation testing and will detect slow or sticking curtains, shutter capping, shutter bounce etc.

All data is output to the PC screen, but due to size limitations, not all error diagnostics can be displayed on the simple TFT or LCD.

Due to screen size restrictions, some of the errors & diagnostics shown can be a little cryptic. A more detailed explanation will be displayed on the PC screen.

LCD The first row are the legends for sensor 2, M and 1.

Second shows the calculated reading for each sensor in milliseconds, third row is in fractional seconds.

The last row, C2 & C1 show the time each curtain took to travel the distance between the outer sensors, in milliseconds.

If ‘B’ appears in the top row of the LCD, it is indicating that shutter bounce has been detected.

H or V will be shown briefly on the top row of the LCD, if sensor space has been set to 32mm (H) or 20mm (V). This is overwritten with R (ready) when The Shutter Tester is able to perform another test.

If ‘F’ appears in the top row of the LCD, it indicates that a successful flash sync was detected.


LCD showing a successful test

The PC screen gives a similar display to the TFT screen.

Each time the camera shutter is fired, the display will automatically update.


PC screen showing completed test.

### Testing screen. (Simple Screens)

)

Whilst in the Testing Screen, pressing the Blue Button will cycle between the Detailed and the two Simple screens. Firmware 4.0.0.3 onwards adds a fourth oscilloscope screen

The two simple screens, show the basic results, but in a much larger typeface.
Note: - Due to limited space, flash & error details are not displayed.

Scope Screen. (From firmware 4.0.0.3)
Each sensor is shown as a trace and are indexed from the first ‘seen’ input.
A high horizontal line indicates the sensor is blocked.
The line drops and continues horizontally, when a sensor is seen. Raising again when the sensor is blocked. A white vertical line indicates when the flash is fired.
The screen auto-scales depending on the total duration of the shutter cycle.

It can be seen in the photo below, that the flash fired when all three sensors are exposed to light, thus the curtains fully open.


In the second photo the white line shows that sensor one had already been covered by the curtain before the flash was fired.


Buttons.

Whilst in the Testing Screen, the Buttons have the following functions: -

Pressing the White Button will show the average of (up to) the last ten readings.

Pressing the Yellow Button whilst in the Average Screen, will clear the accumulated average readings. Note this only works whilst in the Average screen.

Pressing the Green Button will go to the Light-meter Utility

Pressing the Black Button will go to the Alignment & Setup Utility.

Pressing the Red Button will go to Optical LED Shutter Tester Utility.

Pressing the Blue Button cycles between Detailed & Simple TFT displays.

Note: - Due to limitations of memory & speed, error checking cannot be performed for every permutation. So strange readings may occur for example, if fingers are waved across the lasers or a seriously badly behaving camera is being tested.

Testing Shutters.
For Focal-Plane horizontal shutters, the three sensors should be spaced the correct distance apart (32mm for horizontal cloth shutters, or as specified in the camera service manual). They should be around centre height of the film gate. With the Lasers also aligned in a similar manor.

For vertical shutters, the spacing is normally 20mm, with the sensors arranged vertically.

The Shutter Tester will then record multiple raw measurements from these three sensors during the shutter cycle to calculate the shutter speed and diagnose any issues that could not be seen with the naked eye. Shutter capping or sticky curtain, for example.

Within the build documents & Photrio thread, you will see many examples of how to mount the sensors and Lasers.

When using Single Sensor mode, just Senor 1 is used. It can be useful for testing cameras like the Box Brownie, for example. If used for focal-plane shutters, the Laser/sensor pair can be placed anywhere within the film gate. This can be useful, for testing the mirror lift mech. For example, if the mirror is slow to lift and still within the film-gate when the curtains are open, a slower exposure would be recorded with the sensor at the top of the film gate, compared to that when in the middle. Note only raw readings will be given when using a single sensor. As this is an uncalculated value, the result will progressively under-read as shutter speed increases.

Leaf Shutters are a bit trickier to test. One has to measure the opening time of the shutter (T1) the fully open time (T2) and the closing time of the shutter (T3)
The formula to give shutter speed is then Te (effective exposure time) = T2 + (T1+T3)/2

For these measurements, Sensor 1 and Sensor 2 are used (Sensor M is not used).
Sensor 1 should be aligned dead centre of the leaf shutter, with Sensor 2 aligned on the extremity of the leaf opening. Ensure Leaf Shutter has been selected in the Alignment menu and also the Sensor Space parameter is set.

A quick alternate to lest leaf shutters, is to use Single Sensor Mode. you can measure the speed at the edge of the diaphragm stopped down by two to get a very close approximation of Te (effective shutter speed) with a single measurement. (Thanks to ic-racer for this information).

Note Leaf shutter functionality is experimental and has not been fully tested in the real world. So please be mindful of this when testing.
Data Logging.

The recorded test data can optionally be recorded for reference or analysis, either to an SD card, via USB or both.

Recording to SD card.
The SD card must be pre-formatted in a PC to FAT32 and must be no larger than 32Gb.

SD card must only be inserted when The Shutter Tester is powered off.

From firmware 4.0.0.3, data logging behaviour has changed.
If no existing data files are found on the SD card during boot, new files are created.
If existing csv files are found on the SD card, the existing files are kept and data is appended to them. To delete the existing files, press the White button during boot.

Note Older firmware deletes any old data files and creates new ones on boot.

This data can then be opened in a spreadsheet. Google sheets, Excel or Libre Office (a free & very good alternate to MS Office) for viewing & analysis.

Recording to USB.
Test results can be written as a csv file to the USB port. (also written to SD as described above if USB&SD is selected).

A suitable capture program will be required. Microsoft Excel has an add-in called ‘Data Streamer’ which will monitor and record the USB output directly to Excel.
Here is a video describing its setup & operation. Relevant information starts at 7.30
(5) Arduino Data Logging with Microsoft Excel Data Streamer - YouTube (https://www.youtube.com/watch?v=yGRhx2JYyOc&ab_channel=ChefJeffPhD)

An alternate is to use something like CoolTerm which records the output. Relevant information starts at 7.30
Save Arduino Serial Data to TXT, CSV, or Excel Using CoolTerm | Step-by-Step Guide (https://www.youtube.com/watch?v=j1x54ixEFak&ab_channel=ChefJeffPhD)

Data recording options, selected in Alignment Menu.
Screen – output is sent to the PC screen (using a suitable serial monitor) in a humanised display format.
ScreenSD – output is sent as above and a csv log file is written to the SD card.
USB – a csv log file is sent via the USB port. Note the humanised PC screen will not be displayed.
USB&SD csv log file is sent both to the USB port and SD card. Note the humanised PC screen will not be displayed.

Note :- whilst the file written to the SD card will be ‘clean’ without any additional text, some errors and messages are sent to the USB port (initial power-on, for example) and will be captured by a USB data logger.

Average Logging.
The running average is sent to SD/USB. This can be reset in the Averages screen.
The full average data is saved to the SD card and/or USB (Averages.csv) only when the White Button is pressed.


MS Excel Data Streamer

Testing Flash.
Connecting the Shutter Tester to the camera’s flash socket will allow testing of the flash sync.
If a flash connection is detected, the tester will give a report after each shutter test.
It will detail the flash fired time in relation to the curtain travel & opening and whether flash sync is ok or not.

The report allows accurate setting of the camera flash contacts, to ensure the flash is trigged at the correct time.
The PC screen & detailed tft screen will show the full report. A less detailed report is shown on the simpler tft display. The Scope screen gives a very good graphical representation of flash.
Limitations of the LCD mean ‘F’ will be displayed if successful flash sync was seen

Note: - Flash sync is measured between the two outer sensors, so ensure the flash timing is not set at extremes of time measurements, else actual flash use may not be in sync.
Light-meter Utility.

TFT Light-Meter screen


The Light-meter Utility will show the Lux light level and EV, based on 100 iso, in the range EV 0 to 15
The calibration value of the sensor is also shown. If the user has access to a calibrated Lux meter, calibration of the shutter tester light meter can be achieved by pressing Yellow Button or Green Button to change the calibration figure between the value of 0.94 and 1.44. Default setting is 1.20

The displayed light-meter reading is automatically updated as the light level changes.

The TFT shows an EV chart, based on 100 iso from EV 5 to 16. If the light-meter reading falls between 5-15, the corresponding EV row will be highlighted.

Note :- Light-Meter reads from EV 0 to 15 only.

A full EV chart is included at the end of this document.

Pressing the Black Button will exit the utility.

Pressing the Green Button will increase calibration value.

Pressing the Yellow Button will decrease calibration value.

The LCD shows Lux, EV, Cal value & button legends.

LCD showing Light-meter screen


PC screen showing Light-meter screen

Note:- DO NOT use the lasers as a light source. The user will have to provide their own light. Maybe a dimmable LED light panel or a photographic continuous light. Note some LED panels are PWM (which cause flickering) rather than current controlled, so can create issues and cause continually changing values.

Link to a good web recourse for measuring light & EV

Understanding Exposure Value, with calculator and EV chart (including for third stops) (scantips.com) (https://www.scantips.com/lights/evchart.html)

Optical Shutter Tester.
For full instructions on using the Optical Shutter Tester, please read the user guide for the stand-alone version.

The notes below are just a brief overview.


LCD screen when Optical Shutter Tester is selected

The LED matrix can be accessed by pressing the Red Button.

It works in the same way as the old idea of photographing a CRT (old fashioned television screen), the strobing effect can give an indication of the camera’s shutter speed. It is not terribly accurate so should be used as an indication only. Whilst it shows shutters that are slower than the set speed, it will not show shutter speeds that are faster than the set value.

The matrix will display the speed 1/30s and then start strobing a row of LEDs moving to each new row at 1/30s intervals.

When photographing, or looking though the film gate of a film camera, if the shutter speed is correct, one or two rows of LEDs should be seen.

If more than two rows of LEDs are seen, it is an indication that the shutter speed is slow.

Pressing the Red Button will increase the strobing speed to the next standard shutter speed. Each shutter speed can be tested in a similar manor.

For a digital camera, take a photo & review it. For a film camera, open the back of the camera and look through the film gate when taking a photo.

Camera & tester set at
1/30s | 1/60s | 1/125
1/250s | 1/500s | 1/1000s

### Computer Screen Display

Similar information as shown on the TFT can be displayed on the computer screen.
For this, a computer program called ‘Arduino IDE’ will be required. See separate document of how to install this program. You can use another serial monitor program if you wish.

In the top drop-down box, select your board and com-port. Note: - a new install of Arduino IDE will not recognise an ESP32 board. Just select Nano.
Select ‘Serial Monitor by clicking the icon as shown.
The Serial Monitor window will be small, so drag the bar up, to make it larger
Select the correct baud rate of 115200 for Esp32.


The display follows a similar format to that of the TFT, but sometimes with more information.

Shutter bounces will be shown, as well as flash sync report.

Averages are updated and displayed. The number of cumulative tests used to calculate the average are shown (in this picture, 3 can be seen).

A maximum of ten individual tests are used to calculate the average. After this, the oldest is lost from the calculation and the latest reading added.

Note :- Output to a USB data-logger and a humanised PC display cannot be used simultaneously, as they both use the same USB port.


Accuracy of The Shutter Tester.
There has been much comment on the accuracy of DIY shutter testers, and I agree with all of them.
Of all of the free tester designs & code I have looked at, not one discusses or accounts for the fundamental reason for inaccuracy. We are trying to measure a single photon, for practical purposes it has a width 0, with a sensor, whether it be a Light Dependant Resister (LDR) or a light switching transistor, which has width. Thus, one measures not only the width of the curtain gap, but also that of the sensor hysteresis.

As an example, a horizontal focal plane shutter with sync speed of 1/30s will have full curtain opening (we measure the curtain slot as 32mm between sensors).
With sensor spacing of 32mm, it gives us a ratio of 1:32 (assuming a 1mm sensor).

Now, take this to 1/500s. The slot width will be 2.25mm, so the ratio is now 1:2.25

So we see, as the speed increases (in reality the speed stays the same, it is the slot width that narrows), the ratio reduces, sensor width becomes an increasing part of the measurement, at 1/500s it adds almost 50% onto the reading!

Similarly, when I look at pre-built testers available today, not one of them discusses the issue above. Having not tested them myself, I cannot say whether the designer understands and accounts for the issues described above.

How do we correct for these errors? There is no simple solution. In the example above, this was for a flash sync speed of 1/30s. One cannot just add a bias or fixed calibration value. What if the sync speed is 1/25s, or the curtains are not adjusted to give specific gaps.

Some cameras also increase the curtain gap as the shutter travels. This is to even exposure as the curtains accelerate from stationary to their maximum speed across the film-gate.

The simplest way to reduce this error is to minimise the sensor area. However, light still has to get to the sensor, so making a mask with a hole can only be so small. Looking at the old professional testers form the 70s. They were filled with logic & counter chips, before the dawn of embedded microcontrollers.

They cleverly had bespoke LDRs which were long, but thin, hidden behind a long thin slot. This way much light in the same plane as the shutter could fall onto the sensor. Of course, these sensors are long out of production today and even then, as they still had width, would introduce error.

How does The Shutter Tester solve this issue? Using a fast, modern microcontroller, The Shutter Tester takes (up to) twelve separate readings during the shutter cycle. These readings are then verified and a computed shutter speed is calculated using the power of the microcontroller and an algorithm, to arrive at the actual shutter speed.

However, as a caveat, one must not get hung up on ultimate shutter accuracy. An older camera without electronic timing, relies on springs and clockwork. Temperature, humidity & how many times the shutter is fired in succession, will all vary the results. Trying to get an older camera spot on, will drive you mad. Just strive for consistency within the iso tolerance.

We also have to consider when and where to take the measurements. The curtains start from a speed of zero and accelerate. Depending on spring tension, they may continue to accelerate before hitting the end-stop. Or the spring may tire and they slow down part way through travel. The second curtain may be tensioned differently or snag slightly during its travel. So ‘accuracy’ can only go so far and one tester design may give slightly different results to another, but both maybe considered accurate.

Shutter Speed. We often use the term Shutter Speed, when we really mean exposure. In reality, it is the time before second curtain release, thus the gap between first and second curtain which determines exposure. The speed of the curtains should remain as constant as possible. In this document Shutter Speed has been used to mean exposure.

### An extract from a kosmo foto article

An extract from a kosmo foto article, detailing shutters and the testing of them. I agree with every word, which is why the multitude of DIY shutter testers available, either to purchase or make oneself, are simply inaccurate at higher speeds.

"The real switch of the sensor from light to dark comes not at the actual time of the curtain moving against the sensor, but at time when the actual light stream is reduced to what the sensor believes is dark, and sensor may have some inertia too. Also, the point of switching from light to dark is not the same as the point of switch from dark to light. So, sensors have their own characteristics that affect metering.

In this case we can reach an important conclusion: the shorter metered time, the more influence physical features of the device has on accuracy. In other words, the shorter the time measured, the more likely there will be an error in the metering".

And for leaf shutters, things get worse for leaf shutters

"And finally the case of the shortest speed. Leaves open – leaves close. No delay. Shutter did not stay in the fully opened position. And in this case the result of metering is not dependent on the shutter! The result is dependent on device characteristics only! In Picture 5 I show three possible levels of the switching sensor: L1, L2, L3. Using those levels we can get three values of the metered time t1, t2, t3. And all the values will be correct. But they will reflect not the shutter speed, but the internal setting of the metering device".


"And now some final conclusions:

- The metered value always contains an error.
- With a faster shutter speed, the margin of error in the metered value is greater.
- Never use as the correct value the metered value based on the fastest shutter speed, especially for leaf-shutter cameras"

Below is a diagram and explanation of leaf shutter testing

ISO table showing shutter speed tolerance.


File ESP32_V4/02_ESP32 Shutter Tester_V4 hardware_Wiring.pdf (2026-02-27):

## Doc V1.5

## ESP32 Hardware & Wiring_V4 05/02/2026

This document should be read alongside

# Schematic diagram. Note: - Schematics show a bare board, rather than it sitting in the Expansion board.

# ‘Build a Box’ document. Details how to mark out, cut and mount everything into a project box.

It also has photos detailing the finished wiring.

All of the boards are pre-made; you will not have to solder the components yourself. Most boards will also have the header pins pre-soldered. The GY-302 (light-meter) and the LED matrix require the header pins soldered. Soldering is also required for the buttons, flash socket and external connectors, if you choose to use them.

JST HX cables are used to connect the different modules to the breakout board. They make a neat solution and fit tightly to the header pins on the modules, so do not work loose like Dupont wires.

There are many 3.3V, 5V & GND power connections. These will not all fit into the breakout board screw-terminals. It will be necessary to connect them in groups with a choc-block or similar, then take one wire to the screw terminal.

Whilst it is not good practice to mix voltages, there is no way to avoid this, as some modules require 3.3V and others 5V. Please take care to ensure the correct voltage is supplied to each module and on the correct pin.

Light-meter, LED matrix and LCD all require 5V. If not using these modules, then 5V wiring is not required.

An optional pcb is available, which replaces the expansion board. They route all of the tFT wiring on the pcb, thus making wiring easier.
They can only be posted within Europe, due to postage costs. See or post on Photrio, for more details.

Ensure you pay particular attention to the polarity of the connections. The boards are clearly marked.

The LCD is marked Vcc and is connected to 5V. (Red wire) and GND, (Black wire)

The GY-302 Light Sensor is marked Vcc and is connected to 5V (Red wire) and GND, (Black wire)

The Laser tx board is marked as S (3.3V) and - (GND) Do not connect anything to the centre pin.
On many Laser boards, the Laser barrel is only held to the board by its wires. This means it can easily be knocked out of alignment. Consider using hot-glue or similar to affix the Laser barrel to the board.

The Sensor (rx) board is marked VCC (3.3V) and GND. The centre pin is marked OUT, which is wired to one of the input pins on the ESP32 Expansion/breakout board.

Be very careful when fitting the receiver sensor into the board. Refer to the photograph. The little lens must be pointing towards the header pins on the board.

Note – The sensor & Laser boards are designed to work from 5v, but normally work fine from 3.3V.
However it has been found that if the wiring is long or thin, the sensors may not trigger correctly. In which case they may safely be wired to the 5v supply.

The TFT is marked VDD (3.3V) and GND (0V). The TFT board LED pin is also connected to 3.3V

JST HX connectors.
Using the kit containing separate plastic shells and pre-made wires is the easiest option. The wires can then be assembled in the correct colour order.

Note: - The kit does not include Brown wires, or an 8-way connector.

The cheapest solution is to use Red for both 3V and 5V power, but BE VERY careful that the TFT is connected only to 3V.

Update -Touch functionality has been added, so two 7-way connectors from the kit can be used to make a 14-way connector. The plastic lip on the connectors will need to be trimmed so they will sit side-by-side. An alternate is to purchase a separate 8-way connector and a 5-way connector from the kit. They then sit either side of the unused pin at position 9.

Important Note: - wiring colours have slightly changed since these photographs were taken.
Where you see an Orange wire, use Blue instead.


This is the encoder, showing the correct wiring colour sequence. NOTE the Orange wire shown here. Use Blue instead.
(Ignore the pre-wired connector to the right).


Connection to the TFT screen using an 8-way connector.(Ignore The pre-wired JST HX connector to the right).
The next pin is not used and the remaining pins are for touch and are wired as pre the schematic.

As described above, you can use an 8-way connector (purchased seperatley) or two 7-way connectors from the kit. If doing this, the sides of the connectors, where they touch, will need trimming.


Wiring for the TFT screen, encoder and buttons.
Orange terminal connectors have been glued to the board using epoxy resin. Top terminal connectors are +3.3V and 0V

Bottom terminal connectors are not yet connected, but will be 0V and +5V

SD card connections.
The SD card slot on the TFT board can be used for data logging if required. SD card must be formatted FAT32 and be no larger than 32Gb

The tft board does not have a connector fitted for connection to the SD card holder, so a 4-way JST HX socket was soldered onto the board and a slot cut into the project box for insertion of the SD card.


LCD.

The LCD is a legacy from the Arduino unit and cannot display as much information as the TFT or PC screen.
The LCD is depreciated and may not be supported in future firmware updates.

In place of the LCD, a larger font and simplified display have been added to the existing TFT screen, allowing the user the option of detailed or larger simplified display.

Note: - The specified project box is too small to house the LCD.
Flash connections.
The flash connection can be used to test when the flash will fire during the shutter cycle, to ensure it is triggered at the correct time. A suitable cable and 3.5mm socket are detailed in the parts document. Two wires require soldering to the socket.

Note: - only cameras with mechanical flash contacts should be connected.


Connections to 3.5MM jack socket.

Button Wiring.
A black wire is connected to one leg on each button in a daisy-chain and then run to the 0V connector block.
The other leg on each button is connected to the corresponding screw terminal on the breakout board.

The wires used were the same colour as the buttons, except for the Black button, where a grey wire was used and the red button, where a purple wire was used, to ensure they were not confused with +v and 0v


Close up of button wiring. Black wire is common to all buttons and then goes to 0V Grey wire has been used for the Black button and a purple wire for the Red button to avoid confusion with +V and 0V wires.

### Other Module wiring

To connect to the external modules, there are a few choices.

a) use JST XH connectors. These are quite short, so will require additional wires soldered onto them.
b) The neatest solution is to purchase JST HX bare pin connectors (female type) and a crimp tool, to attach them to the end of the multicore cable. Suitable connectors & crimp tools are available on AliExpress. Or solder the wires directly to the module.
c) Solder the multicore cable directly to the module. This is probably the most suitable option.

To connect the other end of the cable to the expansion board, the multicore cable can either be run directly into the project box through a suitable hole and terminated on the Expansion board (most straightforward method), or connectors used.

The below details the use of sockets: -

Extreme care must be used if using plugs & sockets, that dedicated pins are used for 3.3V and 5V. Connecting voltage to a data pin of a module is likely to destroy it.


Wiring for the Light-meter & LCD.
0V bottom large flat pin
+5V is on the bottom right pin
Going anti-clockwise, the next pin is not used,
the next pin is Yellow.
The centre pin is White.

Additionally, the bottom left pin (unused here) has been insulated as it is used for 3V for other sensors.


Wiring for the Light Meter
0V bottom large flat pin+5V Bottom right and anti-clockwise, the next pin for Blue Next pin for Yellow.
Centre pin is White

All pins have been insulated with shrink tube, to ensure no short can occur.

Additionally, the bottom left pin (unused here) has been insulated as it is used for 3V for other sensors.

Sensors & Laser wiring.
All pins, marked as ‘S’ on the Laser boards can be daisy-chained together and connected to +3V The 0V pins can similarly be daisy-chained and connected to 0V

The Vcc pins on the sensor board can daisy-chained together and connected to +3V’
The 0V pins can similarly be daisy-chained and connected to 0V.

The centre pin on each of the sensor boards has its own wire going back to the ESP32 breakout board.
(Yellow, Green or Blue)

The multicore cable can be run directly to the breakout board, or a plug & socket used on the exterior of the project box. Using a plug & socket will allow the sensor frame to be changed, for example from a horizontal to a vertical layout.

If using a plug & socket, an 8-pin version would allow two modules (sensors/Lasers & light meter for example) to both use an 8-pin connector to save money, as they come in packs of 5.

Be very careful with the 3V and 5V wires, ensuring they do not come into contact with any of the data pins.


8 pin Din socket wiring. 0V is the large flat terminal at the bottom.
Red is 3V and used the bottom left pin. (To ensure it is not crossed with the 5V pi used for the other modules)

The pins are very tightly spaced, so the +3V and 0V have been insulated with shrink tube to avoid any short circuits. Blue, Green, Yellow then use the next three pins, going clockwise.

Additionally, the bottom right pin (unused here) has been insulated as it is used for 5V for other modules.

A safer alternate is to use different styles or pin configurations for each of the connectors. For example purchase
8-pin connectors for the sensor board,
5-pin for the Light-Meter.
6-pin for the LED Matrix (this device is more of a curiosity & most people do not include it)
3.5mm jack socket for the flash.

When making the plug connections. It is best to put the plug into the socket before soldering.
This helps keep the pins straight when soldering and also allows you to match the correct pin colours. Do NOT forget to put the plastic outer onto the cable first!

Note: - the plugs do not have 0V pin. The 0v wire is soldered to the semi-circular metal cover, near the strain relief clamp.

Completed Unit.
Note Touch wiring on the tft not shown here and the use of the older wiring colours (orange) used.


### Sensors & Laser mounting

If just testing horizontal shutters, using the block-of-wood frame to hold Lasers & sensors works well. This is an easy way to get up & running. For measuring vertical shutters, the same idea can be used, but obviously the sensors and Lasers must be stacked vertically.

For a finished project, mounting the sensors & Lasers in boxes is the ideal.

O | O | O

[-----------32mm horizontal spacing---------------------]


Sensor rx – showing correct sensor placement.

Note: - To protect the sensors from damage, they can be omitted before the initial power-up. The LED on the module should light, proving connection & polarity is correct. After de-powering, the sensor can then be fitted to the module.

The project is powered via the USB connector on the ESP32 board. No other power is required. Before connecting the USB power lead, check, double check and then treble check all of your connections and the correct orientation of the receiver sensors.

When applying power, the Lasers will shine red and also the red LEDs on each of the rx boards should light.

For the prototype, to make the sensor unit, two pieces of wood were cut, one 40mm high, to mount the Lasers (tx). The other 28mm high, to mount the sensors (receivers, rx) Spacers under the camera (scrap wood, beer mats etc) used to raise different camera models to the correct height.

The Laser & sensor modules were hot-glued to the top of the wood. Hot-glue allows the lasers to be moved for alignment, whilst the glue cools.

The below photo shows the Arduino prototype, which used two sensors and Lasers.

Using this method is a quick simple way to get everything working.
3d printable parts are now available, including a case (rather than using the project box) and Sensor & Laser boxes.


Prototype shutter tester with two Lasers.

In this example, wires (taken from an Ethernet cable) are directly soldered to the Laser boards, rather than jumper wires being used.

This simple design works perfectly well & the third Laser & sensor for the ESP32 version easily added.


Here is the 158-90-60 project box with just the TFT display.
(It is displaying the Simple Screen, which has been added to replace the LCD).


Here is the ESP32 Shutter Tester in a larger 200-120-75 project box, with both TFT & LCD. The LCD is mounted in an acrylic frame and bolted to the top of the project box.


The original block of wood Laser and sensor frame can be seen at the top, now with three sensors and Lasers.

Below the camera is the film-gate sensor and LED light box used instead of the Lasers.

Note: - Lasers work far better than a LED light source and film-gate sensor. Some people like experimenting with the ‘traditional’ way of using a film-gate-sensor, thus details of how to make one are detailed in a separate document.

Here are some pictures from the Photrio thread, showing some of the designs people have made, many are the Arduino versions.


Compact version in 3d printed case


Inside the compact version.


Lego version, testing a medium format camera.


3d printed version. Note lasers & sensors are arranged diagonally, 32mm spacing horizontally & 20mm vertically. This way the same sensor frame can be used for horizontal or vertical shutters.
It does however make it a little trickier to line up the film-gate with the Lasers.

Lego :o)


Horizontal or vertical shutters. Switch toggles horizontal or vertical Lasers.

Chopping board used for base and electrical socket boxes used to house sensors & Lasers.


Mask added to the Lego version, for better accuracy at higher shutter speeds.

Simple ‘block of wood’ sensor frame.


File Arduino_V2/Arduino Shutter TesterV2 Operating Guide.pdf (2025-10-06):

Doc V2.0.1 06-10-25

### Arduino Shutter Tester Version 2

Build a shutter tester for Focal Plane shutters - Cheap, Easy & it Works | Page 23 | Photrio.com Photography Forums (https://www.photrio.com/forum/threads/build-a-shutter-tester-for-focal-plane-shutters-cheap-easy-it-works.197756/page-23)

First use after loading firmware

Assuming the build has been completed correctly and the firmware loaded, when the Shutter Tester is connected to the computer via the USB cable, The LCD should light and display text.

If the LCD lights, but no text can be seen, try adjusting the contrast screw on the back. As an initial setting, turn fully clockwise and then just a small amount back.


User Authentication.
The first time the Shutter Tester is operated, the LCD and PC screen will say ‘Auth Code’ and display a number. This number must be sent via private message to Niglyn. The quickest way is via the Photrio forum, link at the top of the page.

A user key will be sent by return and must be entered into the shutter Tester. This is only required once.

To enter the user key, press the ‘Display Average Button’. Keeping the button pressed will rapidly increase the displayed number. A quick press will increase the number by 1.

When the supplied user key matches that displayed, press the ‘Reset Average’ button.

If you overshoot the number, there is no way to decrease it. If you are close to 9999 then keep pressing, as the number wraps round to 0. If your number is low, press ‘Reset Average’ button. The Shutter Tester will restart and you can try again.

Once entered correctly, the screen will say ‘Correct’. After a short while the screen will blank & go dark. After some internal number crunching, the Shutter Tester will spring back into life.

Note an LCD screen is not required for authentication or general use. All output, (other than Laser Alignment Utility) is also sent to the PC screen using the Arduino IDE Serial Monitor, as described further down.

Laser Alignment Utility

To enter the Alignment utility, apply power and when the splash screen is shown, press & hold the ‘Display Average’ button. Once in the utility, release the button.


This utility will allow checking and aligning of the laser and receiver pairs by giving an indication on the LCD whether or not the sensor can see the laser beam.

When the laser is shining onto the receiver and the receiver can see the laser, the LCD will report ‘Seen’ When the laser is blocked, by a piece of card or your hand, the LCD will say ‘blocked’.


There are two different versions of the sensor, referred to as ‘original’ and ‘new’. Both look identical, so there is no way to tell by looking, which type they are. The only difference between the two is that one has an inverse output to the other. If the Laser Alignment Utility seems to be working backwards, it means you have the old type of sensor.

If there is no change at all to the LCD screen, then check all the wiring. Lasers should be shining Red and the LED on the receiver boards should be on. There is no protection from incorrect wiring or sensor orientation on the boards, so incorrect wiring will most likely result in a damaged board or sensor.

Note: - You will probably find that the Laser barrel is not affixed to the pcb other than by its connecting wires. Adding a bit of hot-glue, or another suitable adhesive, will hold it in place.

To exit the utility, press ‘Reset Average’ button.

Note: - The Laser Alignment utility is only displayed on the LCD, no output is sent to the PC screen.

Normal Use

After the initial splash screen, the LCD will change to the testing Screen.


Testing screen

There are two columns. Each column will show the calculated exposure measurement from each of the laser and receiver pair.

The measured exposure is shown in milliseconds (0.001 of a second) one decimal place.

The fractional value is then shown below

The last value in each column C2 & C1 show the time Curtain1 and Curtain2 took to travel between the two sensors in milliseconds.

Each time the camera shutter is fired, the display will automatically update.

The letter ‘R’ will appear on the top right of the LCD (and ‘Ready…’ on the PC screen) when the Shutter Tester is ready for a new test. The sensors must be blocked, for this to happen.

If ‘B’ appears in the top right corner, it is indicating that shutter bounce has been detected.

Pressing the ‘Display Average’ button will show the average of (up to) the last ten readings.

Pressing the ‘Reset Average’ button will clear all of the accumulated readings, when changing shutter speeds, for example.

Note: - Due to limitations of the Arduino memory, error checking is limited. So strange readings may occur, for example fingers waved across the lasers or a seriously badly behaving camera is being tested.
LED light, including computer monitors, can also be problematic if it is PWM controlled. The Shutter Tester may see this as sensor changes.

Computer Screen Display

Far more information can be displayed on the computer screen, than that of the LCD alone.
For this, a computer program called ‘Arduino IDE’ will be required. See separate document of how to instal this program.


The display follows a similar format to that of the LCD, but with more information.

Shutter bounces will be shown as well as if flash sync has occurred at the given speed.

Averages are updated and displayed. The number of cumulative tests used to calculate the average are shown (in this picture, 3 can be seen).

A maximum of ten individual tests are used to calculate the average. After this, the oldest is lost from the calculation and the latest reading added.

As with the LCD, pressing the ‘Reset Average’ button will clear the historic data and new averages will be calculated using new test data.

V 2.01

Updated wording stating PC screen can also be used for authentication.

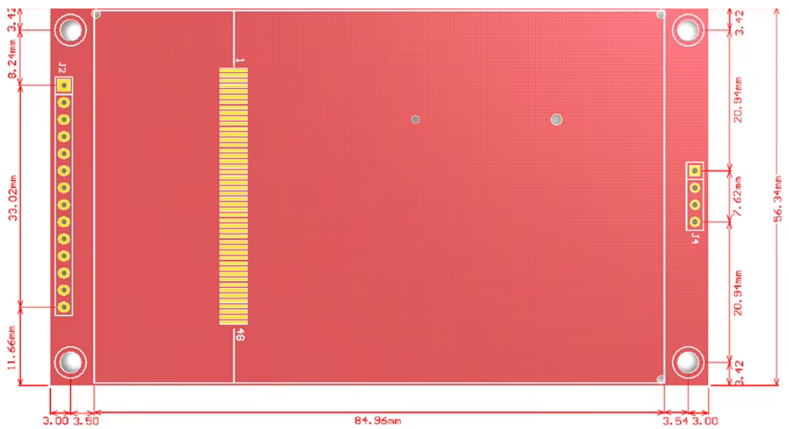
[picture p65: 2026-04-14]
ESP32_V4/3d_print_files/ShutterTesterCase3dPrinted 3_5/photos/Screenshot 2026-04-12 164130.png

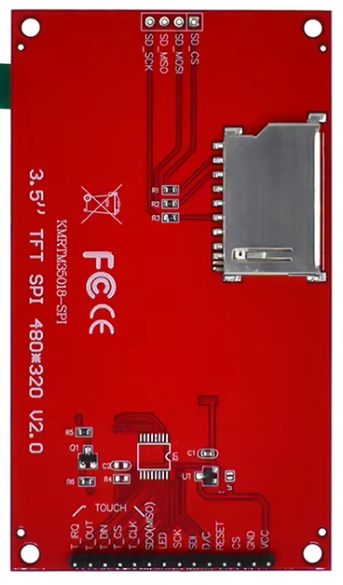
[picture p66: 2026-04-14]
ESP32_V4/3d_print_files/ShutterTesterCase3dPrinted 3_5/photos/Screenshot 2026-04-12 164802.png

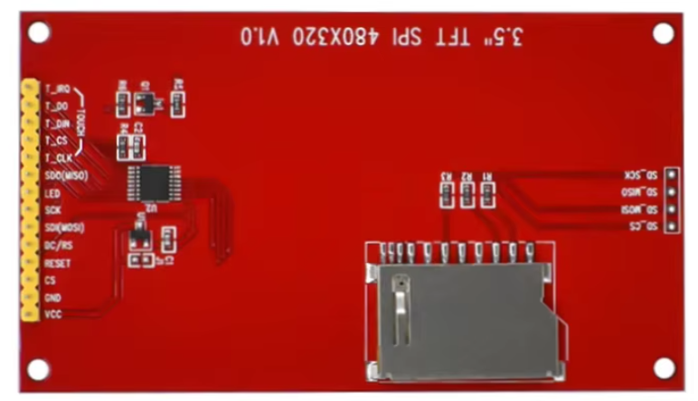
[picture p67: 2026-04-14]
ESP32_V4/3d_print_files/ShutterTesterCase3dPrinted 3_5/photos/Screenshot 2026-04-12 164223.png

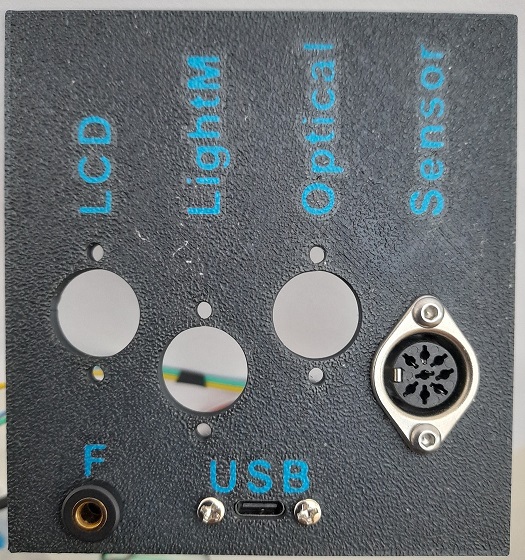
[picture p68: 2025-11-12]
ESP32_V4/3d_print_files/ShutterTesterCase3dPrinted/20251112_153204.jpg

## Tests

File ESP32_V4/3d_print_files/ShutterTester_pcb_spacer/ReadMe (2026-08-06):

THe pcb spacer bolts to the end of the pcb, extending it's lengh so it can be mounted on the existing tft mounting bolts.

More details are found in the Shutter_Tester_pcb document.

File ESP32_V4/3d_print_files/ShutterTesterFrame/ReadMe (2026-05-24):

These files are for the sensor and Laser enclosure (boxes) and the base they fit into.

21/04/2026 The recess in the base was made to fit the AliExpress table I ordered, which was 88mm x 88mm.

However it was reported that a recent table purchased was 90mm x 90mm. Therefore the recess for the table has been increased in size to 91mm x 91mm.

24/05/2026 new file added shutter_tester_base103_smaller
This file prints a base that is reduced in length from 220mm to 206mm, which is suitable for smaller printers.

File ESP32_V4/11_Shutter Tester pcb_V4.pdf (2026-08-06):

GitHub repository where all documentation & code can be found. billbill100 (github.com) (https://github.com/billbill100)

## ESP32 Shutter Tester pcb V1.1 06/08/2026

As an alternative to using the aliexpress screw-terminal expansion board to mount the ESP32 module, a bespoke pcb has been designed.

All the hard work is done, just got to pcbway from the link below to order the V2 pcb.

The Shutter Tester - Share Project - PCBWay (https://www.pcbway.com/project/shareproject/The_Shutter_Tester_ee9e8adf.html)

Click ‘add to basket’. Note the price for 10 boards is the same as for 5. With just a slight postage increase.

The pcb is very similar in design to the aliexpress screw-terminal expansion board, but has the advantage that both the ESP32 module and the tft screen plug directly into the pcb, with all required connections for the tft routed directly on the pcb.

The board (V1 or V2) also has additional 3, 5 and 0v connectors, making wiring simpler.
All of the other connections for sensors etc are broken out onto screw-terminals in the same way as the aliexpress expansion board.

Wiring and using the pcb is identical to that of the aliexpress expansion board, but eliminating the 14 wires for the tft.

The pcb requires header sockets and screw terminals, to be assembled and soldered by the user.

The updated V2 board allows the either the standard NodeMCU32 dev board with pin row spacing of 22.86mm 0.9in or the wider 25.4mm 1.0in board to be used.

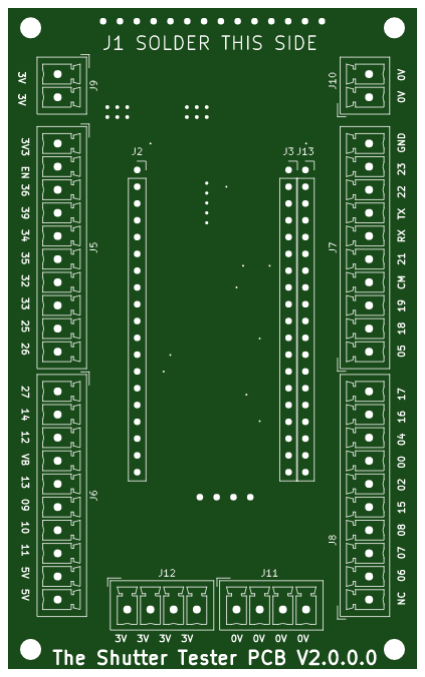
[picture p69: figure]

Add the 19-pin header connector in position J3 for the narrower, OR J13 for the wider ESP32 dev board.

VERY IMPORTANT DISCLAIMER
The V1 board has been ordered and used successfully without error or issue.
The V2 board has NOT yet been tested, whilst there should not be any errors on it (only J13 was added) no responsibility can be taken should an unforeseen error be found with the board.

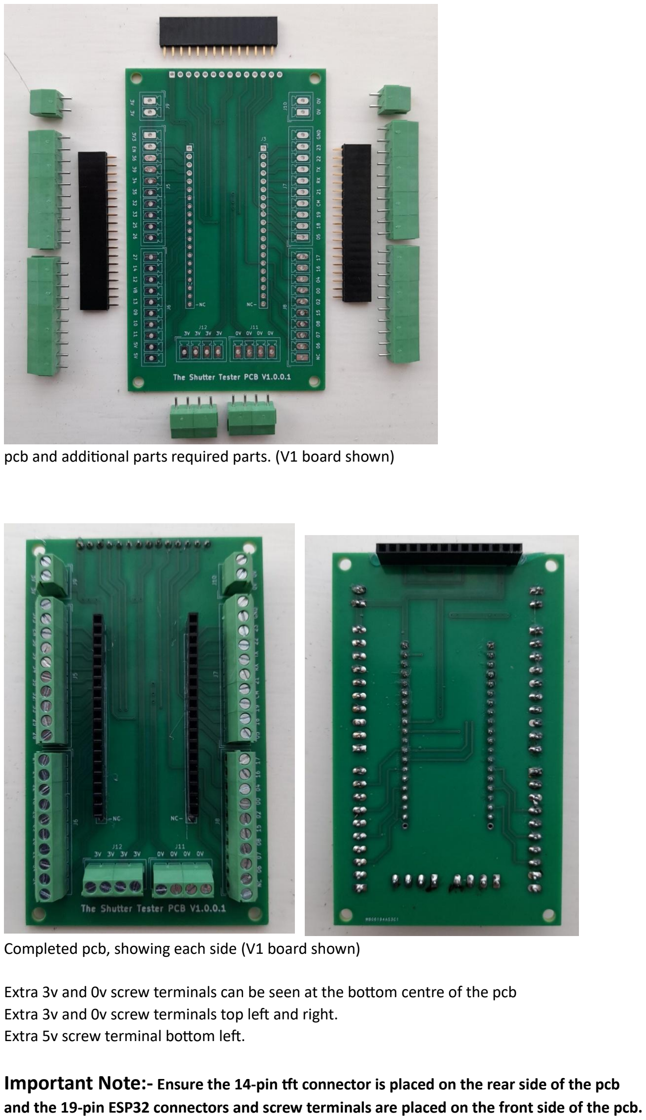
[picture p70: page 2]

pcb and additional parts required parts. (V1 board shown)

Completed pcb, showing each side (V1 board shown)

Extra 3v and 0v screw terminals can be seen at the bottom centre of the pcb Extra 3v and 0v screw terminals top left and right.
Extra 5v screw terminal bottom left.

Important Note:- Ensure the 14-pin tft connector is placed on the rear side of the pcb and the 19-pin ESP32 connectors and screw terminals are placed on the front side of the pcb.

Populate J3 OR J13 with a single 19-pin header connector. DO NOT put a connector in both.

The pre-drilled holes at the top of the pcb align with the holes in the tft, and can be secured using the same tft mounting bolts.

M3 bolts & nuts can be used in the bottom holes, as stand-offs. With the heads hot-glued to the tft pcb.
This method is shown in the ‘Build a Box’ document

A better solution is to 3d print the tft pcb spacer.
This bolts onto the underside of the pcb, with the rectangular stand-offs facing down, (using the round holes on the 3d printed part) using M3 X12mm bolts or similar.
with the elongated holes fitting onto the tft mounting bolts.

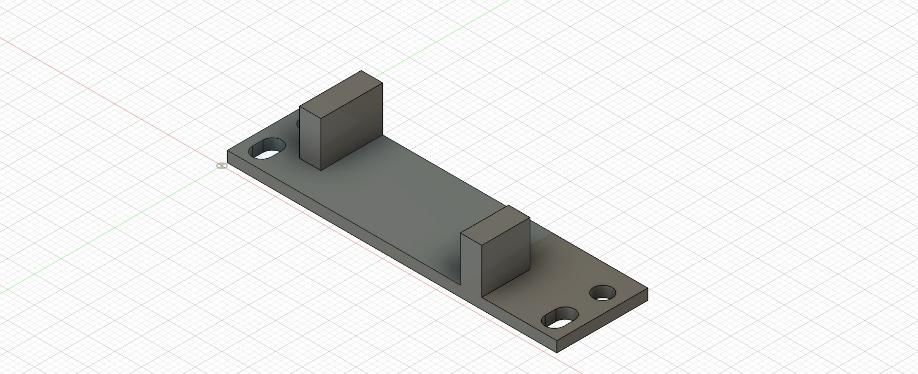
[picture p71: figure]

3d printed pcb spacer

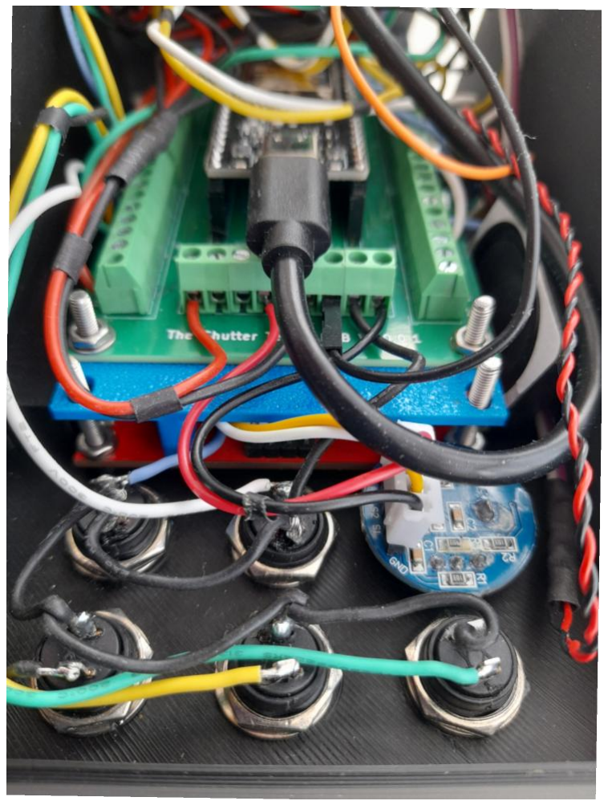
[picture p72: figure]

Pcb spacer, printed in blue, fitted in position.

## Parts required for the pcb

Screw terminals, 3.5mm spacing.
100PCS 3.5mm 2P 3P Screw Terminal Block Connector KF350 (https://www.aliexpress.com/item/1005002724741195.html)

Screw terminals, 3.5mm spacing.
They come in 2 or 3 way and slide together to form larger ways.
4 x 10-way, 2 x 4-way and 2 x 2-way are required.

So one pack of 2-way connectors are required, which is enough for three boards.
(buy 1 pack of 2-way and one pack of 3-way, which will be plenty, if making more than 3)

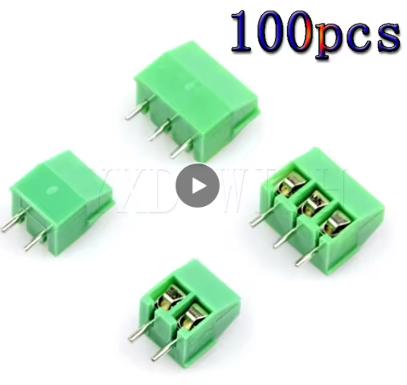
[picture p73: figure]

Header sockets, female.

10PCS 2.54mm Single Row Female Header 1x2p to 1x40p Pin Connector (https://www.aliexpress.com/item/4001198421663.html)

2 of 19-way required and
1 of 14-way required.

They come in packs of 10, so one pack of the 19-way will make 5 boards. (buy 2 packs of 19-way to make 10 boards)

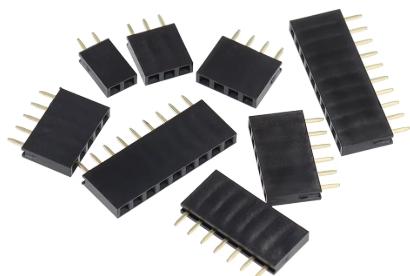
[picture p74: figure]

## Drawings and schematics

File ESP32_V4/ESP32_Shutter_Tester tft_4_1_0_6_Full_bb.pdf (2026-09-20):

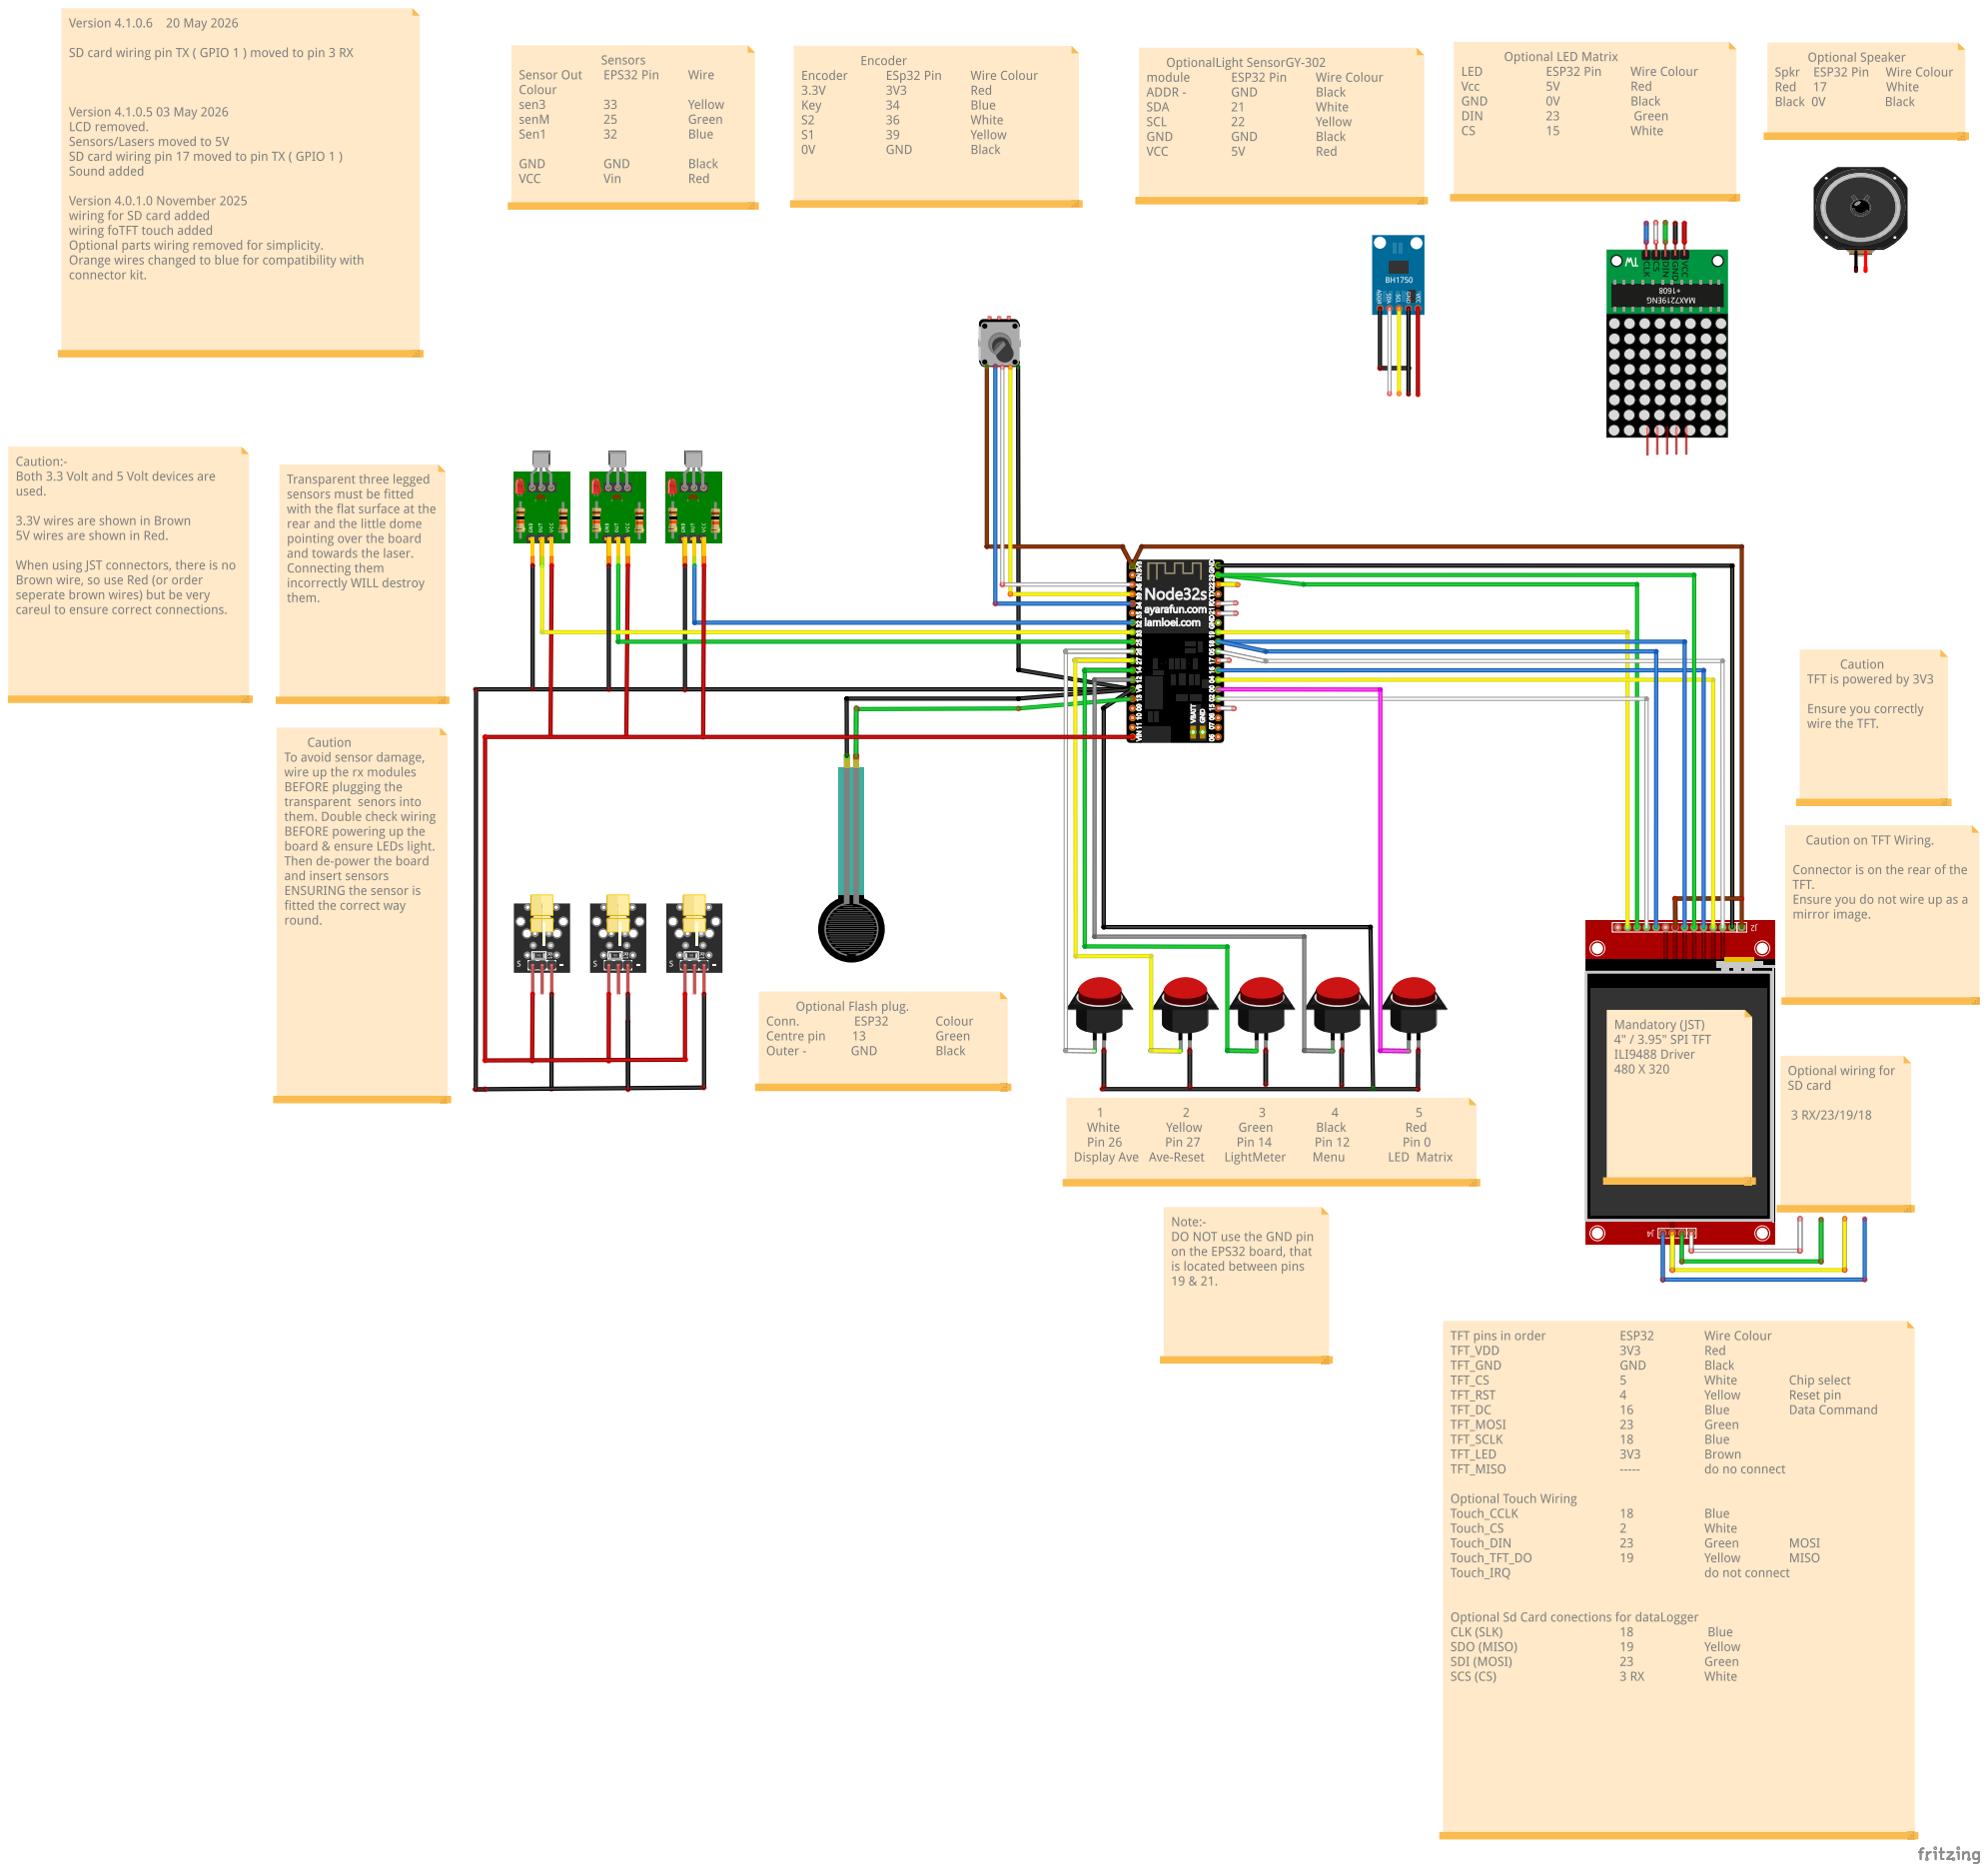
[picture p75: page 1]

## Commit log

2023-09-03 Add files via upload
    This code version should work for the newer laser receivers, which annoyingly are now supplied with a revered logic output.
2023-09-03 Add files via upload
    This code uses the earlier laser receiver, which has a reversed logic output compared to the newer receiver.
2023-09-03 Update Arduino_shutter_tester_parts.txt
    Parts list for Arduino version of Shutter Tester
